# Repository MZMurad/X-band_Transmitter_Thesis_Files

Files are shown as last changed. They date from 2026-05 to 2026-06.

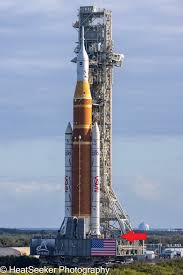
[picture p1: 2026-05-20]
GNU_Radio_Files/BPSK_TX_RX/Images.jpeg

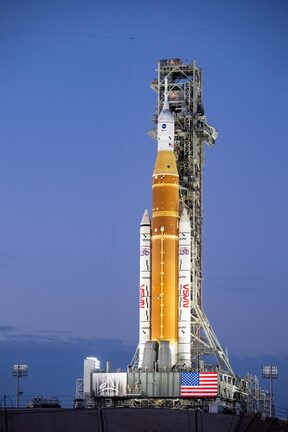
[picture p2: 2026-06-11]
GNU_Radio_Files/QPSK_TX_RX/images.jpeg

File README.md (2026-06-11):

# X-band_Transmitter_Thesis_Files
This is a repo for all the files used and mentioned in my thesis

The file structure:
    
- Hardware: Includes all KiCad schematics and PCBs, all are KiCad projects
- All GNU Radio flow graphs wthin the GNU labeled folder
- The python folder contains all python used for plotting and test automation for the HP5262A VNA and the HP8562A Spectrum Analyzer
- The data folder contains all data collected over the span of this thesis

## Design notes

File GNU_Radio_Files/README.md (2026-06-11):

# GNU Radio
The above two folders contain the flow graphs for a BPSK TX/RX that was used during this project's testing
The second folder contains a differential QPSK TX/RX flow graphs that were used in this project's testing

These files were made with the LimeSDR Mini 2

To use the files:
- After cloning the git, within each TX and RX flow graph there is either a file source or a file sink
- Each of these blocks must be given a path to a source file (png, jpeg, or text) and a sink file
- The sink file will always be overwritten, make sure the sink file has the same extention as the source file
- Before running the graphs on a full system ensure that you can connect two SDRs with a cable (TX -> RX) and that the files are operational without any hardware in the loop

Some trouble shooting tips
- A lot of the time it is helpful to understand what each block does, make sure you read the GNU Wiki. The wiki also has examples that these files are based on.
- Make sure the gain of the TX and RX stages are in order, the files here have the gains used with hardware in the loop
- The bandwidth of the FLL block and costas loops are very important for synchonization. If you suspect there might be some synchonizing issues it is a good idea to start there
- The Access code correlation block has a threshold value that is set to 0 meaning that the block will only trigger "correct" if there are no bit errors, this is useful but depending on the system in between the SDRs may need to be increased.

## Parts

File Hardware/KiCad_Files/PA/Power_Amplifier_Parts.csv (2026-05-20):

Reference | Value | Datasheet | Footprint | Qty | DNP
C1,C2,C3,C4,C5,C6,C7,C8 | 0.001u | ~ | Capacitor_SMD:C_0402_1005Metric_Pad0.74x0.62mm_HandSolder | 8
C9,C10,C11,C12,C13,C14,C15,C16,C18,C19,C20 | 0.1u | ~ | Capacitor_SMD:C_0402_1005Metric_Pad0.74x0.62mm_HandSolder | 11
C17 | 47u | ~ | Capacitor_SMD:C_1206_3216Metric | 1
IC1 | PMA5-123-3W+ | https://www.minicircuits.com/pdfs/PMA5-123-3W+.pdf | PMA5-123-3W+:QFN50P500X500X100-33N-D | 1
J1,J8 | 32K243-40ML5 | 32K243-40ML5 | 32K243-40ML5:CONN_32K243-40ML5_RBG | 2
J2,J3,J4,J5,J6,J7 | Conn_01x02_Pin | ~ | Connector_PinHeader_2.54mm:PinHeader_1x02_P2.54mm_Vertical | 6
L1,L2 | 150n | ~ | Inductor_SMD:L_0402_1005Metric_Pad0.77x0.64mm_HandSolder | 2
R1,R2 | 100k | ~ | Resistor_SMD:R_0402_1005Metric_Pad0.72x0.64mm_HandSolder | 2
R3 | 0R | ~ | Resistor_SMD:R_0402_1005Metric_Pad0.72x0.64mm_HandSolder | 1
R4 | 100R | ~ | Resistor_SMD:R_0402_1005Metric_Pad0.72x0.64mm_HandSolder | 1

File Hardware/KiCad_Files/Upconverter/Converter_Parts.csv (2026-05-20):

Value | Reference | Datasheet | Footprint | Qty | DNP
0.1u | C1,C2,C4,C17,C23,C25,C27,C29,C31,C34,C48 | ~ | Capacitor_SMD:C_0402_1005Metric_Pad0.74x0.62mm_HandSolder | 11
10p | C3,C6,C9 | ~ | Capacitor_SMD:C_0201_0603Metric_Pad0.64x0.40mm_HandSolder | 3
1000p | C5,C7,C8,C16,C37,C40,C43,C46 | ~ | Capacitor_SMD:C_0402_1005Metric_Pad0.74x0.62mm_HandSolder | 8
2p | C10,C11 | ~ | Capacitor_SMD:C_0402_1005Metric_Pad0.74x0.62mm_HandSolder | 2
0.47u | C12 | ~ | Capacitor_SMD:C_0603_1608Metric_Pad1.08x0.95mm_HandSolder | 1
22n | C13 | ~ | Capacitor_SMD:C_0603_1608Metric_Pad1.08x0.95mm_HandSolder | 1
1000p | C14 | ~ | Capacitor_SMD:C_0603_1608Metric_Pad1.08x0.95mm_HandSolder | 1
10p | C15 | ~ | Capacitor_SMD:C_0603_1608Metric_Pad1.08x0.95mm_HandSolder | 1
120p | C18,C21 | ~ | Capacitor_SMD:C_0603_1608Metric_Pad1.08x0.95mm_HandSolder | 2
1u | C19 | ~ | Capacitor_SMD:C_0603_1608Metric_Pad1.08x0.95mm_HandSolder | 1
0.1u | C20 | ~ | Capacitor_SMD:C_0603_1608Metric_Pad1.08x0.95mm_HandSolder | 1
10p | C22,C24,C26,C28,C30,C32,C35,C38,C39,C42,C45 | ~ | Capacitor_SMD:C_0402_1005Metric_Pad0.74x0.62mm_HandSolder | 11
DNP(1u) | C33 | ~ | Capacitor_SMD:C_0402_1005Metric_Pad0.74x0.62mm_HandSolder | 1
4.7u | C36 | ~ | Capacitor_SMD:C_0402_1005Metric_Pad0.74x0.62mm_HandSolder | 1
10u | C41 | ~ | Capacitor_SMD:C_0402_1005Metric_Pad0.74x0.62mm_HandSolder | 1
1u | C44,C47 | ~ | Capacitor_SMD:C_0402_1005Metric_Pad0.74x0.62mm_HandSolder | 2
LED | D1 | ~ | LED_SMD:LED_0603_1608Metric_Pad1.05x0.95mm_HandSolder | 1
32K243-40ML5 | J1,J2,J4,J5,J6,J8,J9,J10 | 32K243-40ML5 | 32K243-40ML5:CONN_32K243-40ML5_RBG | 8
MM8030-2610RK0 | J3,J16,J17,J19 | MM8030-2610RK0 | MM8030_2610RJ3:MM8030-2610RK0_MUR | 4
Conn_01x05_Pin | J7 | ~ | Connector_PinHeader_2.54mm:PinHeader_1x05_P2.54mm_Vertical | 1
Conn_01x03_Pin | J13,J14,J15,J20,J21 | ~ | Connector_PinHeader_2.54mm:PinHeader_1x03_P2.54mm_Vertical | 5
Conn_01x07_Pin | J18 | ~ | Connector_PinHeader_2.54mm:PinHeader_1x07_P2.54mm_Vertical | 1
DNP(4.7n) | L1,L3,L4 | ~ | Inductor_SMD:L_0201_0603Metric_Pad0.64x0.40mm_HandSolder | 3
7.4n | L2,L6 | ~ | Inductor_SMD:L_0201_0603Metric_Pad0.64x0.40mm_HandSolder | 2
10R | R1,R20 | ~ | Resistor_SMD:R_0402_1005Metric_Pad0.72x0.64mm_HandSolder | 2
100R | R3 | ~ | Resistor_SMD:R_0402_1005Metric_Pad0.72x0.64mm_HandSolder | 1
1.8k | R4,R5,R6 | ~ | Resistor_SMD:R_0603_1608Metric_Pad0.98x0.95mm_HandSolder | 3
1.5k | R7 | ~ | Resistor_SMD:R_0603_1608Metric_Pad0.98x0.95mm_HandSolder | 1
10k | R8 | ~ | Resistor_SMD:R_0603_1608Metric_Pad0.98x0.95mm_HandSolder | 1
0R | R9,R12,R13,R14,R19 | ~ | Resistor_SMD:R_0603_1608Metric_Pad0.98x0.95mm_HandSolder | 5
220 | R10 | ~ | Resistor_SMD:R_0603_1608Metric_Pad0.98x0.95mm_HandSolder | 1
470R | R11 | ~ | Resistor_SMD:R_0603_1608Metric_Pad0.98x0.95mm_HandSolder | 1
68R | R15 | ~ | Resistor_SMD:R_0603_1608Metric_Pad0.98x0.95mm_HandSolder | 1
0R | R16,R17 | ~ | Resistor_SMD:R_0201_0603Metric_Pad0.64x0.40mm_HandSolder | 2
5.1k | R18 | ~ | Resistor_SMD:R_0603_1608Metric_Pad0.98x0.95mm_HandSolder | 1
TestPoint | TP1 | ~ | TestPoint:TestPoint_Pad_D1.5mm | 1
TestPoint | TP6,TP7 | ~ | TestPoint:TestPoint_Pad_D1.0mm | 2
MFBP-00094PSM | U1 |  | Thesis_Marki:QFN-32_EP_5x5_Pitch0.5mm | 1
MFBA-00004PSM | U2 |  | Thesis_Marki:QFN-32_EP_5x5_Pitch0.5mm | 1
ADF5355BCPZ | U3 | https://www.analog.com/media/en/technical-documentation/data-sheets/ADF5355.pdf | ADF5355BCPZ:CP-32-12_ADI | 1
MM1-0222LSM-2 | U6 |  | Thesis_Marki:QFN-16_EP_3x3_Pitch0.5mm | 1
APM-7516PSM | U8,U10 |  | Thesis_Marki:QFN-24_EP_4x4_Pitch0.5mm | 2

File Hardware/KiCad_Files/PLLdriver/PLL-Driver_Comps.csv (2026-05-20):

Reference | Value | Datasheet | Footprint | Qty | DNP
C1,C2 | 100p | ~ | Capacitor_SMD:C_0402_1005Metric_Pad0.74x0.62mm_HandSolder | 2
C3,C4 | 0.3p | ~ | Capacitor_SMD:C_0402_1005Metric_Pad0.74x0.62mm_HandSolder | 2
C5 | 10p | ~ | Capacitor_SMD:C_0402_1005Metric_Pad0.74x0.62mm_HandSolder | 1
C6 | 1u | ~ | Capacitor_SMD:C_0402_1005Metric_Pad0.74x0.62mm_HandSolder | 1
C7 | 10u | ~ | Capacitor_SMD:C_0603_1608Metric_Pad1.08x0.95mm_HandSolder | 1
J1,J2 | 32K243-40ML5 | 32K243-40ML5 | 32K243-40ML5:CONN_32K243-40ML5_RBG | 2
J3,J4 | Conn_01x02_Pin | ~ | Connector_PinHeader_2.54mm:PinHeader_1x02_P2.54mm_Vertical | 2
L1 | 33nH | ~ | Inductor_SMD:L_0603_1608Metric_Pad1.05x0.95mm_HandSolder | 1
U1 | PMA3-83MP+ | PMA3-83MP+ | PMA3-83MP:DQ1225_MNC | 1

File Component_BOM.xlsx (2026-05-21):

 |  | Up Converter
Value | Discription | Size | Count | Part Link | Part Number
0.1u | Cap | 0402 | 33 | https://www.mouser.com/ProductDetail/TAIYO-YUDEN/MMASU105SB5104KFNA01 | MMASU105SB5104KFNA01
10p | Cap | 0201 | 15 | https://www.digikey.com/en/products/detail/murata-electronics/GRM1885C1H100JA01D/586930 | GRM1885C1H100JA01D
1000p | Cap | 0402 | 15 | https://www.mouser.com/ProductDetail/KYOCERA-AVX/04025A102FAT2A | 04025A102FAT2A
2p | Cap | 0402 | 10 | https://www.mouser.com/ProductDetail/KYOCERA-AVX/04025J2R0QBSTR | 04025J2R0QBSTR
0.47u | Cap | 0603 | 15 | https://www.mouser.com/ProductDetail/KEMET/C0603C474J3RACTU?qs=HoCaDK9Nz5dEncza6kTYlQ%3D%3D | C0603C474J3RACTU
22n | Cap | 0603 | 15 | https://www.mouser.com/ProductDetail/KYOCERA-AVX/0603YC223KAT2A?qs=394Pi71zH6hTiH4tlhTRbQ%3D%3D | 0603YC223KAT2A
1000p | Cap | 0603 | 15 | https://www.digikey.com/en/products/detail/yageo/CC0603KRX7R9BB103/302819?gclsrc=aw.ds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 | CC0603KRX7R9BB103
10p | Cap | 0603 | 15 | https://www.mouser.com/ProductDetail/KEMET/C0603C100F2TACTU?qs=Znm5pLBrcAL25eSJc5nVFw%3D%3D | C0603C100F2TACTU
120p | Cap | 0603 | 15 | https://www.mouser.com/ProductDetail/KYOCERA-AVX/06031U121FAT2A | 06031U121FAT2A
1u | Cap | 0603 | 15 | https://www.mouser.com/ProductDetail/YAGEO/CC0603KRX5R8BB105 | CC0603KRX5R8BB105
0.1u | Cap | 0603 | 15 | https://www.mouser.com/ProductDetail/YAGEO/CC0603MRY5V9BB104 | CC0603MRY5V9BB104
10p | Cap | 0402 | 33 | https://www.mouser.com/ProductDetail/Vishay-Vitramon/VJ0402D100FXCAJ | VJ0402D100FXCAJ
4.7u | Cap | 0402 | 15 | https://www.mouser.com/ProductDetail/KYOCERA-AVX/04023D475MAT2A | 04023D475MAT2A
10u | Cap | 0402 | 15 | https://www.mouser.com/ProductDetail/KYOCERA-AVX/0402ZD106MAT4A?qs=OlC7AqGiEDknQdNq3NcrYg%3D%3D | 0402ZD106MAT4A
1u | Cap | 0402 | 15 | https://www.mouser.com/ProductDetail/KYOCERA-AVX/04023D105KAT2A | 04023D105KAT2A
LED | Diode | 0603 | 5 | https://www.mouser.com/ProductDetail/ams-OSRAM/Q65113A7466?qs=wT7LY0lnAe3Xiz4Rd%252BLMUA%3D%3D | Q65113A7466
32K243-40ML5 | RF Connector | ~ | 8 | https://www.mouser.com/ProductDetail/Rosenberger/32K243-40ML5?qs=ehM%252BESVsXgwT7KyEp9wcmQ%3D%3D | 32K243-40ML5
MM8030-2610RK0 | RF Connector | ~ | 4 | https://www.digikey.com/en/products/detail/murata-electronics/MM8030-2610RK0/4421021 | MM8030-2610RK0
DNP(4.7n) | Ind | 0201 | 15 | https://www.mouser.com/ProductDetail/ABRACON/AIMC-Q0201HQ-4N7H-T?qs=ST9lo4GX8V2VU3SnVgirQg%3D%3D | AIMC-Q0201HQ-4N7H-T
7.4n | Ind | 0201 | 15 | https://www.digikey.com/en/products/detail/coilcraft/0201DS-7N4XJEW/15794125 | 0201DS-7N4XJEW
10R | Res | 0402 | 15 | https://www.mouser.com/ProductDetail/Vishay-Beyschlag/MCS04020C1009DE000 | MCS04020C1009DE000
100R | Res | 0402 | 15 | https://www.mouser.com/ProductDetail/Bourns/CR0402-JW-101GLF | CR0402-JW-101GLF
1.8k | Res | 0603 | 15 | https://www.mouser.com/ProductDetail/Vishay/TNPW06031K80DETA | TNPW06031K80DETA
1.5k | Res | 0603 | 15 | https://www.mouser.com/ProductDetail/Bourns/CR0603-JW-152ELF?qs=wOX%252BDVkMoZSu%252BfxzrcTI6Q%3D%3D | CR0603-JW-152ELF
10k | Res | 0603 | 15 | https://www.mouser.com/ProductDetail/Vishay-Beyschlag/MCT06030D1002BPW00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 | MCT06030D1002BPW00
0R | Res | 0603 | 15 | https://www.mouser.com/ProductDetail/Vishay/CRCW06030000Z0EI | CRCW06030000Z0EI
220R | Res | 0603 | 15 | https://www.mouser.com/ProductDetail/Bourns/CR0603-JW-221ELF | CR0603-JW-221ELF
470R | Res | 0603 | 15 | https://www.mouser.com/ProductDetail/Bourns/CR0603-JW-471ELF?qs=sGAEpiMZZMtlubZbdhIBIN4pzcyTCT7wAWvNAcavl80%3D | CR0603-JW-471ELF
68R | Res | 0603 | 15 | https://www.mouser.com/ProductDetail/Vishay-Beyschlag/MCT06030C6809FP500 | MCT06030C6809FP500
0R | Res | 0201 | 15 | https://www.mouser.com/ProductDetail/Vishay/RCA02010000ZSEDSR | RCA02010000ZSEDSR
5.1k | Res | 0603 | 15 | https://www.mouser.com/ProductDetail/Bourns/CR0603-FX-5101ELF?qs=0nF2VnfAjXkzZl7D0jRjmQ%3D%3D | CR0603-FX-5101ELF
ADF5355BCPZ | PLL | ~ | 2 | https://www.mouser.com/ProductDetail/Analog-Devices/ADF5355BCPZ?qs=hpwIUhX6lWz%252By8O4aZ7X5w%3D%3D | ADF5355BCPZ
Header 2.54mm | Connector |  | 20 | https://www.digikey.com/en/products/detail/adam-tech/PH1-10-UA/9830653?gclsrc=aw.ds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 | PH1-10-UA
 |  | PA
Value | Discription | Size | Count | Part Link | Part Number
0.001u | Cap | 0402 | 15 | https://www.digikey.com/en/products/detail/murata-electronics/GRM1555C1H102JA01D/702509 | GRM1555C1H102JA01D
0.1u | Cap | 0402 | 33 | https://www.digikey.com/en/products/detail/murata-electronics/GRM155R71E104KE14D/4905173 | GRM155R71E104KE14D
47u | Cap | 1206 | 15 | https://www.digikey.com/en/products/detail/kyocera-avx/KGM31HR51C476MU/13557231 | KGM31HR51C476MU
PMA5-123-3W+ | PA | ~ | 2 | https://www.mouser.com/ProductDetail/Mini-Circuits/PMA5-123-3W%2b?qs=sqEgtWRSLJ2vtugGWqj06A%3D%3D | PMA5-123-3W+
32K243-40ML5 | Conn | ~ | 2 | https://www.mouser.com/ProductDetail/Rosenberger/32K243-40ML5?qs=ehM%252BESVsXgwT7KyEp9wcmQ%3D%3D | 32K243-40ML5
150n | Ind | 0402 | 7 | https://www.digikey.com/en/products/detail/coilcraft/0402DF-151XJRW/12714460 | 0402DF-151XJRW
100k | Res | 0402 | 15 | https://www.digikey.com/en/products/detail/koa-speer-electronics-inc/RK73H1ETTP1003F/9844156 | RK73H1ETTP1003F
0R | Res | 0402 | 15 | https://www.digikey.com/en/products/detail/koa-speer-electronics-inc/RK73Z1ETTP/9844696 | RK73Z1ETTP
100R | Res | 0402 | 15 | https://www.digikey.com/en/products/detail/koa-speer-electronics-inc/RK73H1ETTP1000F/9844157 | RK73H1ETTP1000F
 |  | PLL-Driver
Value | Discription | Size | Count | Part Link | Part Number
100p | Cap | 0402 | 15 | https://www.digikey.com/en/products/detail/murata-electronics/GRM1555C1H101JA01D/3693829 | GRM1555C1H101JA01D
0.3p | Cap | 0402 | 15 | https://www.digikey.com/en/products/detail/murata-electronics/GQM1555C2DR30WB01D/5881897 | GQM1555C2DR30WB01D
10p | Cap | 0402 | 15 | https://www.digikey.com/en/products/detail/murata-electronics/GRM1555C1H100JA01D/3661907 | GRM1555C1H100JA01D
1u | Cap | 0402 | 15 | https://www.digikey.com/en/products/detail/murata-electronics/GRM155C71A105KE11D/6606086 | GRM155C71A105KE11D
10u | Cap | 0603 | 15 | https://www.digikey.com/en/products/detail/murata-electronics/GRM188D71A106MA73J/4905330 | GRM188D71A106MA73J
32K243-40ML5 | Conn | ~ | 2 | https://www.mouser.com/ProductDetail/Rosenberger/32K243-40ML5?qs=ehM%252BESVsXgwT7KyEp9wcmQ%3D%3D | 32K243-40ML5
33nH | Ind | 0603 | 7 | https://www.digikey.com/en/products/detail/coilcraft/0603CS-33NXGRW/21381206 | 0603CS-33NXGRW
PMA3-83MP+ | Amp | ~ | 2 | https://www.digikey.com/en/products/detail/mini-circuits/PMA3-83MP/16515860 | PMA3-83MP

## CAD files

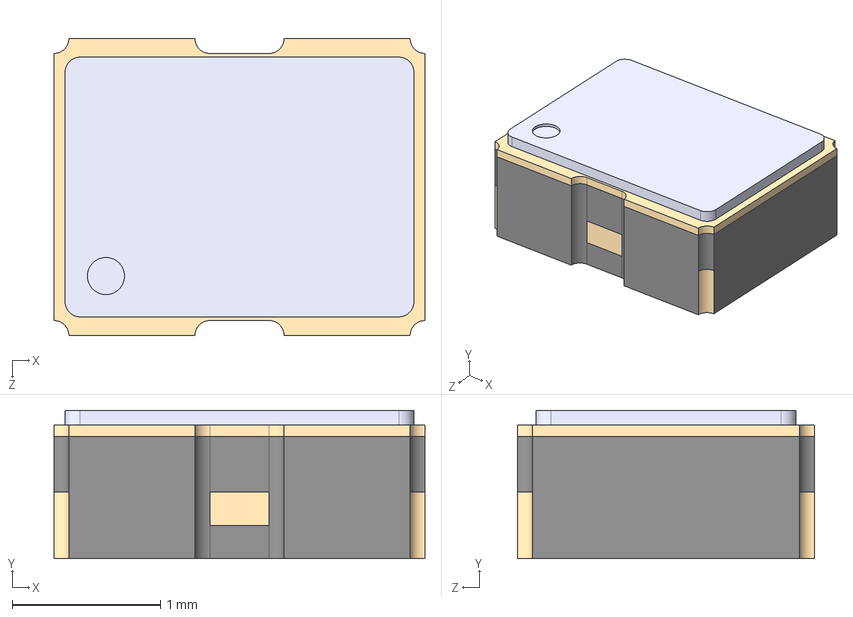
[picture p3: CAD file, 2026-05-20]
Hardware/KiCad_Files/00_OOTparts/ECS-TXO-2520 - TCXO/ECS_TXO_2520_33_250_AN_TR/ECS-TXO-2520-33-250-AN-TR.step
2.50 x 1.00 x 2.00 mm

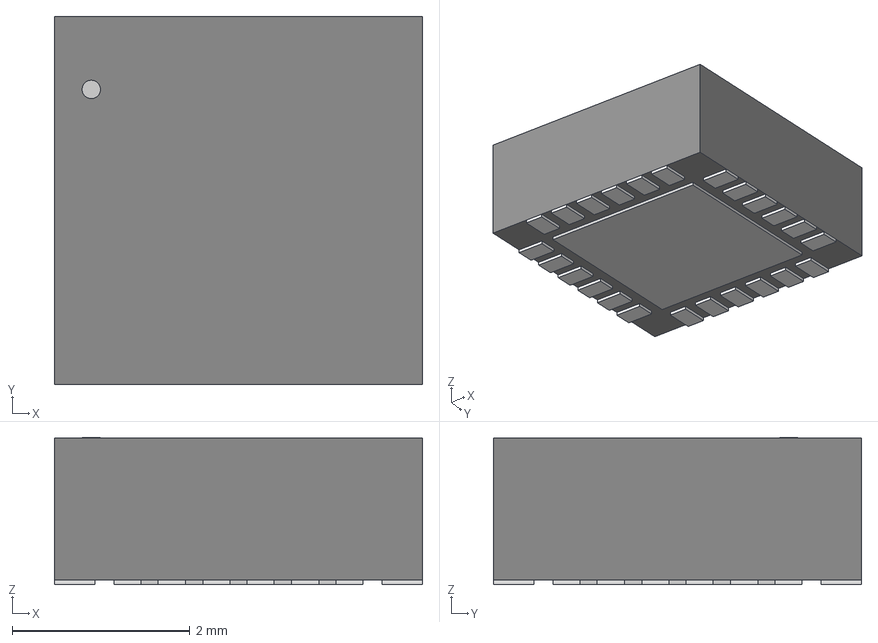
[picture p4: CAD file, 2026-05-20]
Hardware/KiCad_Files/00_OOTparts/S2-LP - Trans/S2_LPQTR/QFN_PQTR_STM.step
4.14 x 4.14 x 1.65 mm

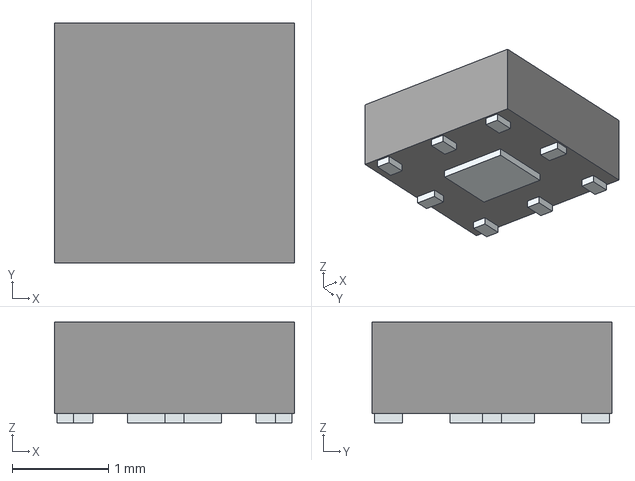
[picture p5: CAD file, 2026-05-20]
Hardware/KiCad_Files/00_OOTparts/Thesis/LIB_MBT-44+ Bias T/LIB_MBT-44+/MBT-44+/3D/MBT-44+.stp
2.50 x 2.50 x 1.05 mm
Pins

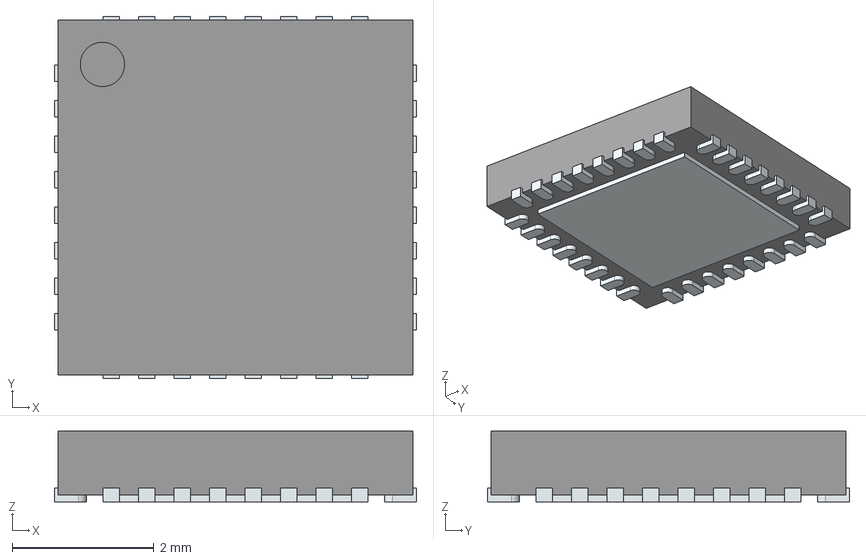
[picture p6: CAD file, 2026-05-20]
Hardware/KiCad_Files/00_OOTparts/Thesis/PMA5-123-3W+ - PA/LIB_PMA5-123-3W+/PMA5-123-3W+/3D/PMA5-123-3W+.stp
5.10 x 5.10 x 1.00 mm
ThermalPin
PinsArrayLR
PinsArrayTB

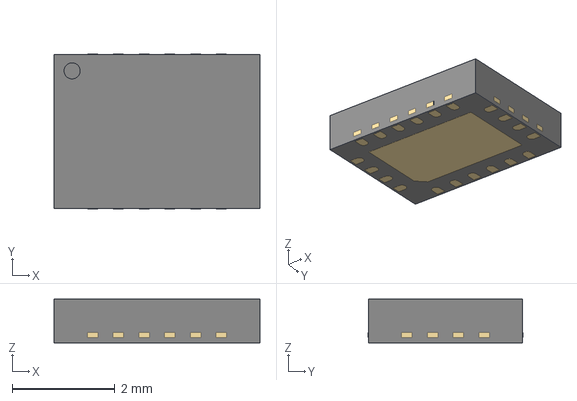
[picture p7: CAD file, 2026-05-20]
Hardware/KiCad_Files/00_OOTparts/Thesis/QPA0001 - Quorvo PA/LIB_QPA0001/QPA0001/3D/QPA0001.stp
4.00 x 3.00 x 0.851 mm

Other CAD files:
Hardware/KiCad_Files/00_OOTparts/Thesis/LIB_MBT-44+ Bias T/LIB_MBT-44+/MBT-44+/Allegro/mbt44.psm
Hardware/KiCad_Files/00_OOTparts/Thesis/LIB_MBT-44+ Bias T/LIB_MBT-44+/MBT-44+/DEHDL/mbt_44_/chips/chips.prt
Hardware/KiCad_Files/00_OOTparts/Thesis/PMA5-123-3W+ - PA/LIB_PMA5-123-3W+/PMA5-123-3W+/Allegro/qfn50p500x500x100-33n-d.psm
Hardware/KiCad_Files/00_OOTparts/Thesis/PMA5-123-3W+ - PA/LIB_PMA5-123-3W+/PMA5-123-3W+/DEHDL/pma5_123_3w_/chips/chips.prt

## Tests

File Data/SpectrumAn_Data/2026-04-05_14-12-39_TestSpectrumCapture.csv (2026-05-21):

Date: 2026-04-05_14-12-39
Center Frequency (Hz): 7600000000.0
Span (Hz): 9700000000.0
RBW (Hz): 2000000.0
Frequency (Hz) | Power (dBm)
2.750000000000000000e+09 | -4.382999999999999829e+01
2.766166666666666508e+09 | -7.132999999999999829e+01
2.782333333333333492e+09 | -4.415999999999999659e+01
2.798500000000000000e+09 | -7.215999999999999659e+01
2.814666666666666508e+09 | -4.315999999999999659e+01
2.830833333333333492e+09 | -7.215999999999999659e+01
2.847000000000000000e+09 | -4.300000000000000000e+01
2.863166666666666508e+09 | -7.065999999999999659e+01
2.879333333333333492e+09 | -4.350000000000000000e+01
2.895500000000000000e+09 | -7.432999999999999829e+01
2.911666666666666508e+09 | -4.265999999999999659e+01
2.927833333333333492e+09 | -7.565999999999999659e+01
2.944000000000000000e+09 | -4.165999999999999659e+01
2.960166666666666508e+09 | -7.350000000000000000e+01
2.976333333333333492e+09 | -4.382999999999999829e+01
2.992500000000000000e+09 | -7.300000000000000000e+01
3.008666666666666508e+09 | -4.432999999999999829e+01
3.024833333333333492e+09 | -7.315999999999999659e+01
3.041000000000000000e+09 | -4.482999999999999829e+01
3.057166666666666508e+09 | -7.550000000000000000e+01
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

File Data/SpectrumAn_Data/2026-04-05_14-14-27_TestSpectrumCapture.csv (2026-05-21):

Date: 2026-04-05_14-14-27
Center Frequency (Hz): 7600000000.0
Span (Hz): 9700000000.0
RBW (Hz): 2000000.0
ID: 8562A GPIB0::18::INSTRFrequency (Hz) | Power (dBm)
2.750000000000000000e+09 | -4.382999999999999829e+01
2.766166666666666508e+09 | -7.132999999999999829e+01
2.782333333333333492e+09 | -4.415999999999999659e+01
2.798500000000000000e+09 | -7.215999999999999659e+01
2.814666666666666508e+09 | -4.315999999999999659e+01
2.830833333333333492e+09 | -7.215999999999999659e+01
2.847000000000000000e+09 | -4.300000000000000000e+01
2.863166666666666508e+09 | -7.065999999999999659e+01
2.879333333333333492e+09 | -4.350000000000000000e+01
2.895500000000000000e+09 | -7.432999999999999829e+01
2.911666666666666508e+09 | -4.265999999999999659e+01
2.927833333333333492e+09 | -7.565999999999999659e+01
2.944000000000000000e+09 | -4.165999999999999659e+01
2.960166666666666508e+09 | -7.350000000000000000e+01
2.976333333333333492e+09 | -4.382999999999999829e+01
2.992500000000000000e+09 | -7.300000000000000000e+01
3.008666666666666508e+09 | -4.432999999999999829e+01
3.024833333333333492e+09 | -7.315999999999999659e+01
3.041000000000000000e+09 | -4.482999999999999829e+01
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

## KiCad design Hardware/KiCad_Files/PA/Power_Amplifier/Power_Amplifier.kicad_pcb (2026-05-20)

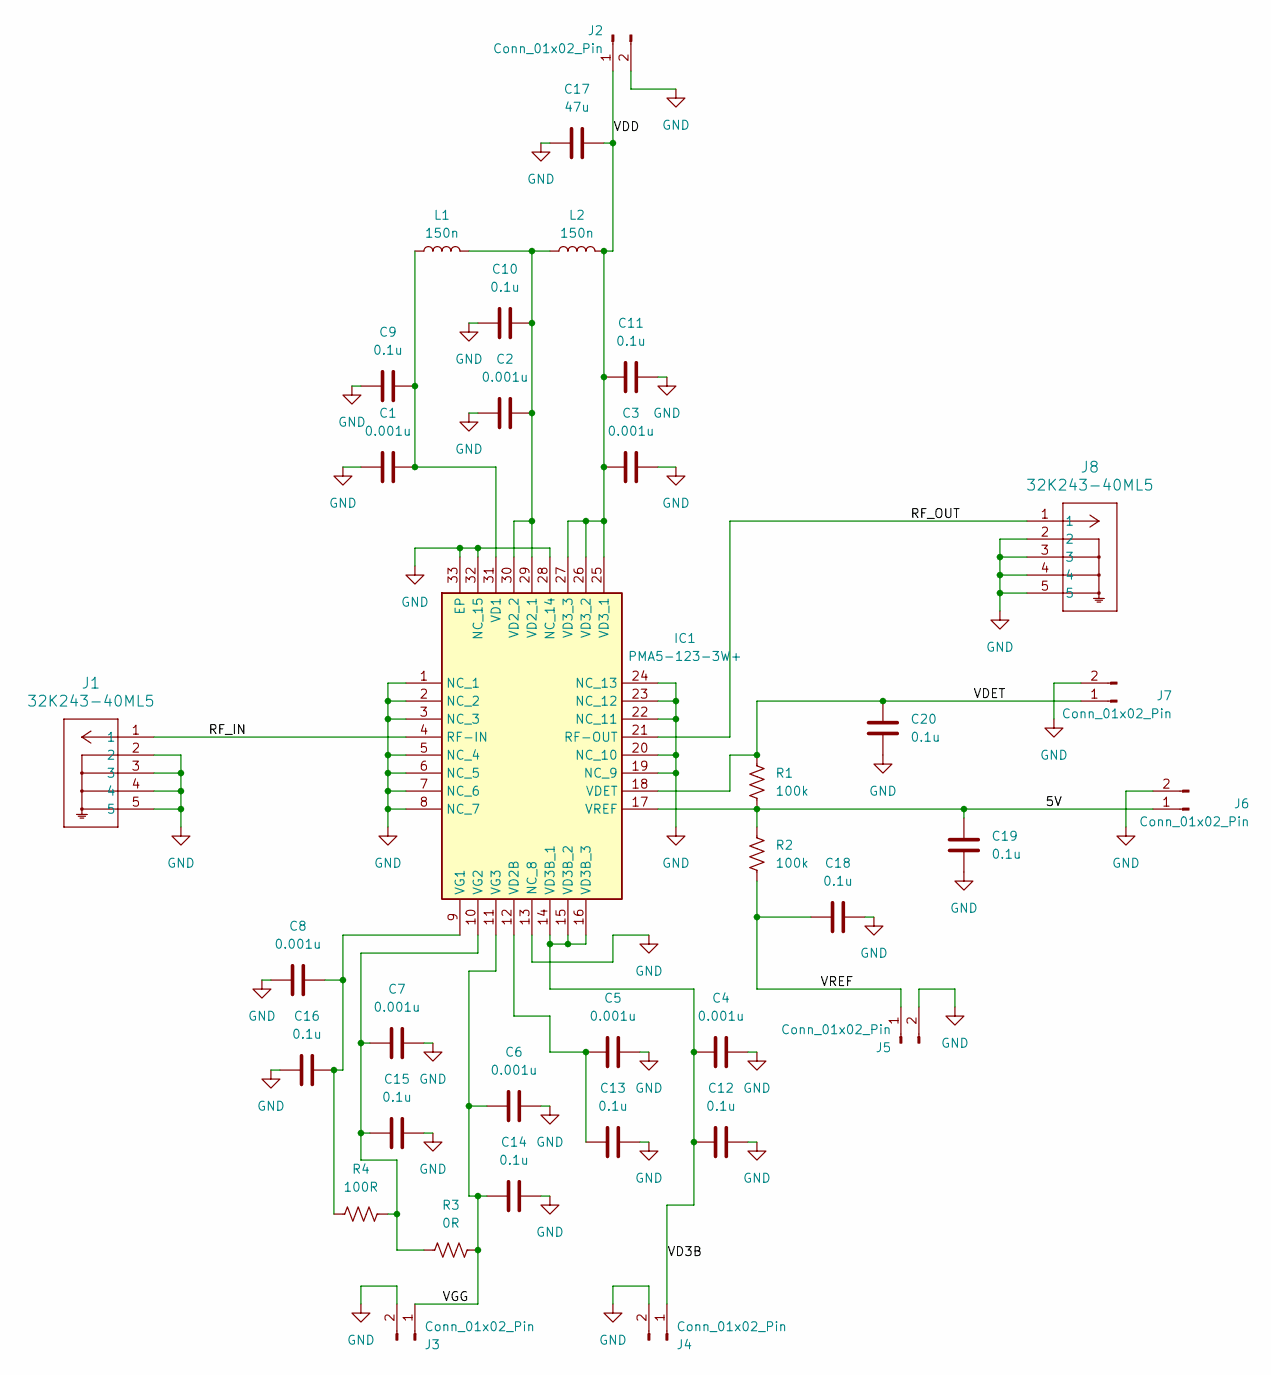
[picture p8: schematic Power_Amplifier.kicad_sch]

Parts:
C1, C2, C3, C4, C5, C6, C7, C8: 0.001u; C_0402_1005Metric_Pad0.74x0.62mm_HandSolder
C9, C10, C11, C12, C13, C14, C15, C16, C18, C19, C20: 0.1u; C_0402_1005Metric_Pad0.74x0.62mm_HandSolder
C17: 47u; C_1206_3216Metric
IC1: PMA5-123-3W+; QFN50P500X500X100-33N-D; Manufacturer_Part_Number PMA5-123-3W+
J1, J8: 32K243-40ML5; CONN_32K243-40ML5_RBG
J2, J3, J4, J5, J6, J7: Conn_01x02_Pin; PinHeader_1x02_P2.54mm_Vertical
L1, L2: 150n; L_0402_1005Metric_Pad0.77x0.64mm_HandSolder
R1, R2: 100k; R_0402_1005Metric_Pad0.72x0.64mm_HandSolder
R3: 0R; R_0402_1005Metric_Pad0.72x0.64mm_HandSolder
R4: 100R; R_0402_1005Metric_Pad0.72x0.64mm_HandSolder

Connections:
/5V: C19.1, IC1.17 (VREF), J6.1, R1.2, R2.1
/RF_IN: IC1.4 (RF-IN), J1.1
/RF_OUT: IC1.21 (RF-OUT), J8.1
/VD3B: C4.2, C12.2, IC1.14 (VD3B_1), IC1.15 (VD3B_2), IC1.16 (VD3B_3), J4.1
/VDD: C3.2, C11.1, C17.2, IC1.25 (VD3_1), IC1.26 (VD3_2), IC1.27 (VD3_3), J2.1, L2.2
/VDET: C20.1, IC1.18 (VDET), J7.1, R1.1
/VGG: C6.2, C14.2, IC1.11 (VG3), J3.1, R3.2
/VREF: C18.2, J5.1, R2.2
GND: C1.1, C2.1, C3.1, C4.1, C5.1, C6.1, C7.1, C8.1, C9.1, C10.1, C11.2, C12.1, C13.1, C14.1, C15.1, C16.1, C17.1, C18.1, C19.2, C20.2, IC1.1 (NC_1), IC1.2 (NC_2), IC1.3 (NC_3), IC1.5 (NC_4), IC1.6 (NC_5), IC1.7 (NC_6), IC1.8 (NC_7), IC1.13 (NC_8), IC1.19 (NC_9), IC1.20 (NC_10), IC1.22 (NC_11), IC1.23 (NC_12), IC1.24 (NC_13), IC1.28 (NC_14), IC1.32 (NC_15), IC1.33 (EP), J1.2, J1.3, J1.4, J1.5, J2.2, J3.2, J4.2, J5.2, J6.2, J7.2, J8.2, J8.3, J8.4, J8.5
unnamed: C1.2, C9.2, IC1.31 (VD1), L1.1
unnamed: C5.2, C13.2, IC1.12 (VD2B)
unnamed: C2.2, C10.2, IC1.29 (VD2_1), IC1.30 (VD2_2), L1.2, L2.1
unnamed: C8.2, C16.2, IC1.9 (VG1), R4.1
unnamed: C7.2, C15.2, IC1.10 (VG2), R3.1, R4.2

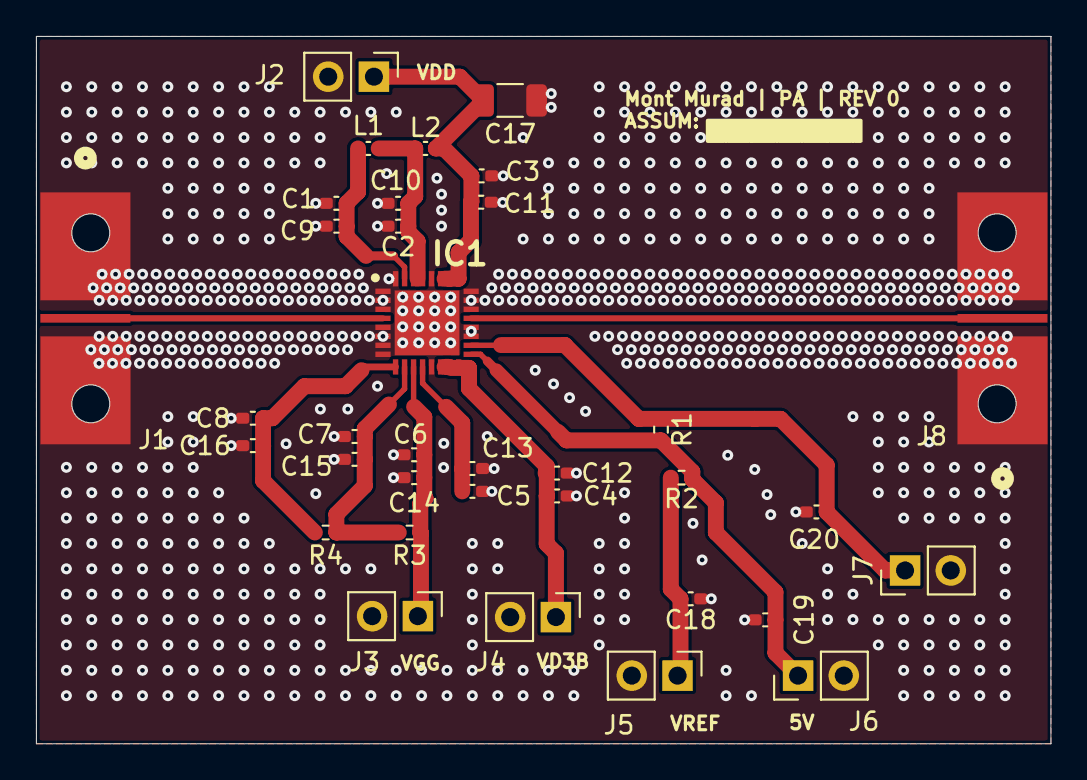
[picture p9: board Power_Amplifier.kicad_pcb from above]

Board: 4 copper layers, 56.4 x 39.3 mm, 35 parts (0 on the bottom side), 14 nets.

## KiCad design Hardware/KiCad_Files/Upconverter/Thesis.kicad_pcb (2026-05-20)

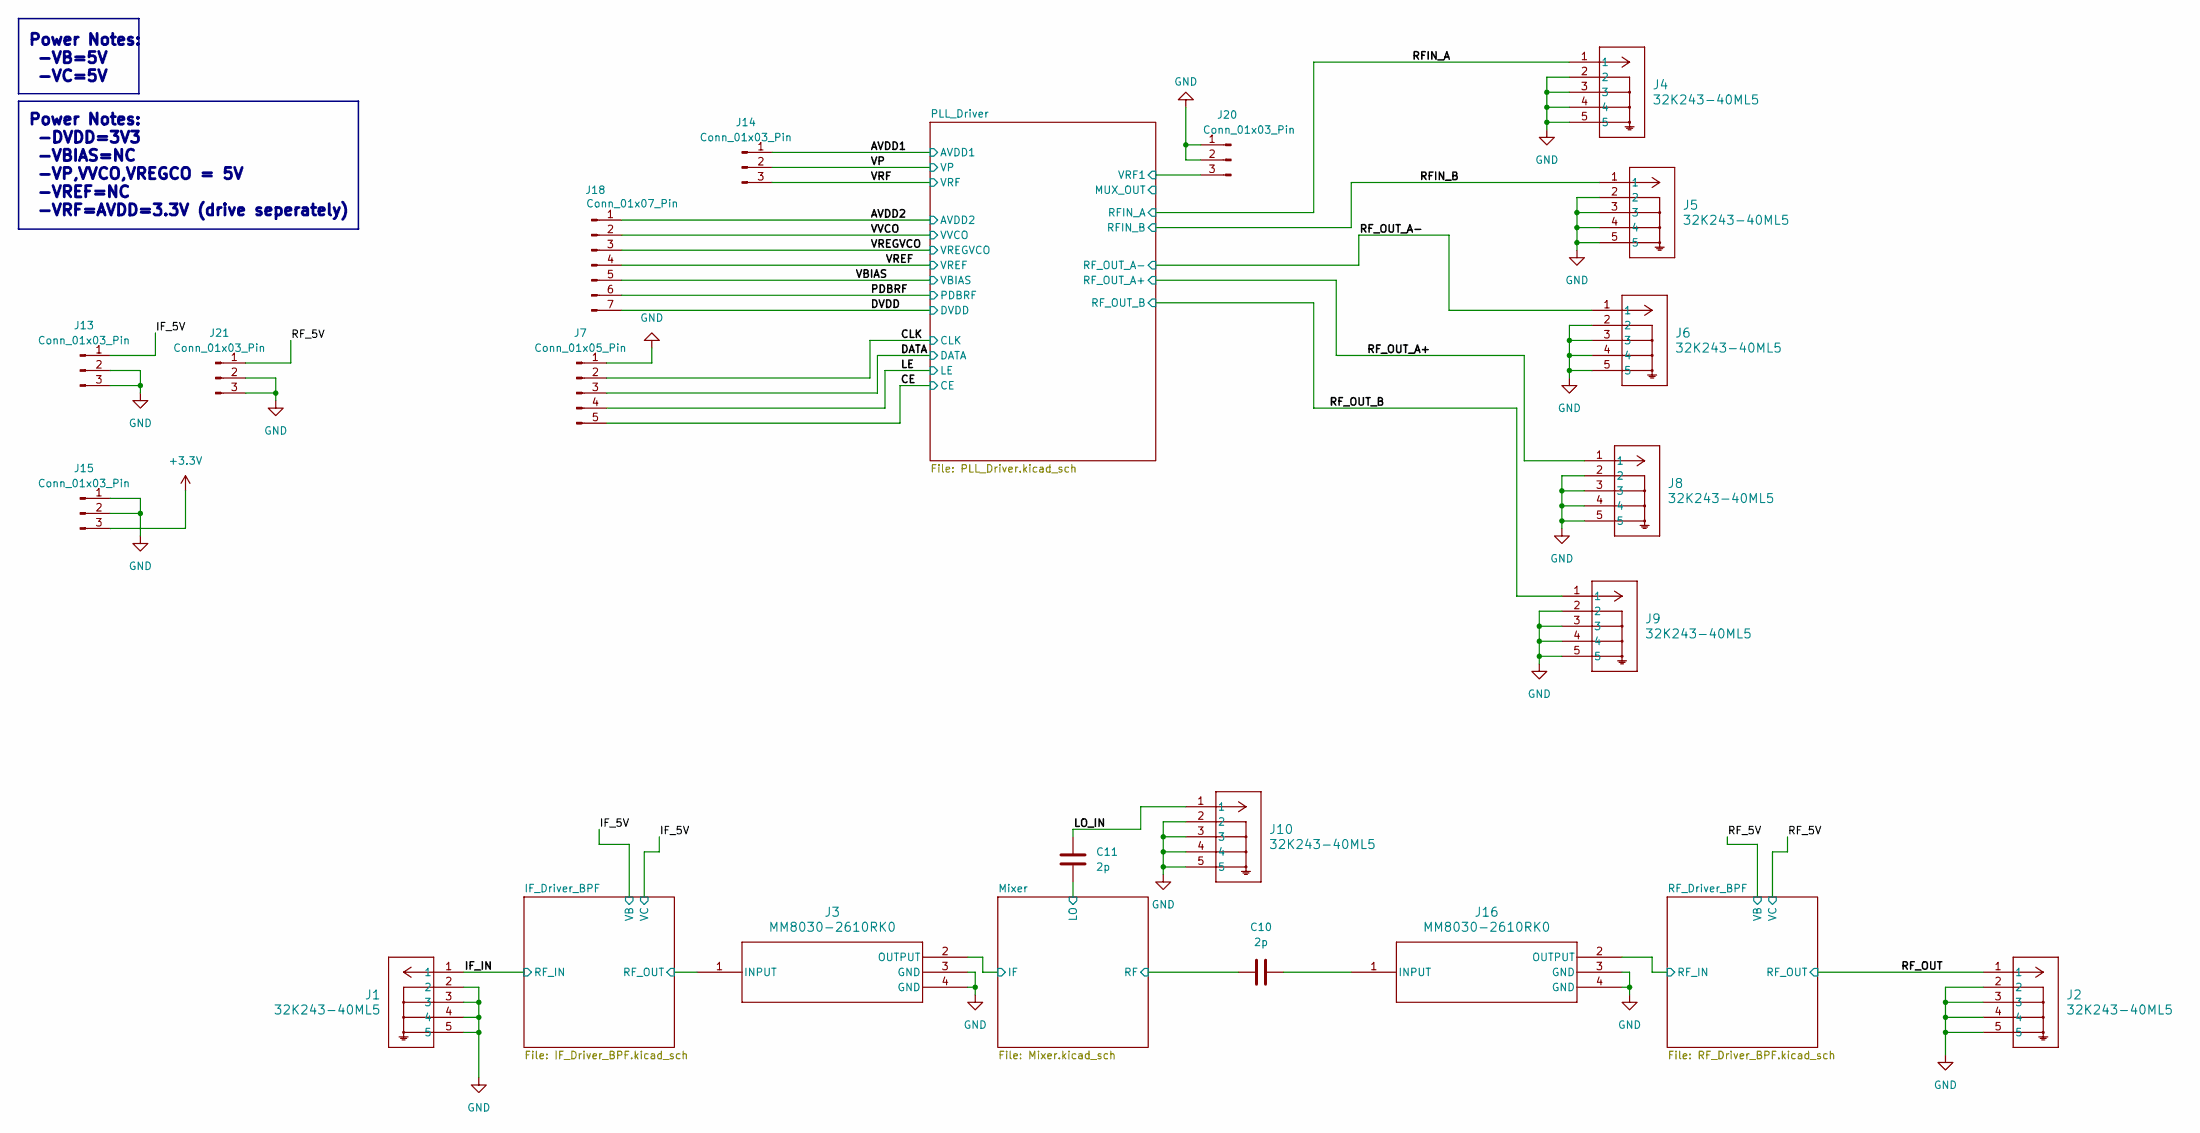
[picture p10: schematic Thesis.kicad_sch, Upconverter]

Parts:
C10, C11: 2p; C_0402_1005Metric_Pad0.74x0.62mm_HandSolder
J1, J2, J4, J5, J6, J8, J9, J10: 32K243-40ML5; CONN_32K243-40ML5_RBG
J3, J16: MM8030-2610RK0; MM8030-2610RK0_MUR
J7: Conn_01x05_Pin; PinHeader_1x05_P2.54mm_Vertical
J13, J14, J15, J20, J21: Conn_01x03_Pin; PinHeader_1x03_P2.54mm_Vertical
J18: Conn_01x07_Pin; PinHeader_1x07_P2.54mm_Vertical

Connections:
+3.3V: J15.3; also elsewhere on the board
/AVDD1: J14.1; also elsewhere on the board
/AVDD2: J18.1; also elsewhere on the board
/CE: J7.5; also elsewhere on the board
/CLK: J7.2; also elsewhere on the board
/DATA: J7.3; also elsewhere on the board
/DVDD: J18.7; also elsewhere on the board
/IF_5V: J13.1; also elsewhere on the board
/IF_Driver_BPF/RF_OUT: J3.1 (INPUT); also elsewhere on the board
/IF_IN: J1.1; also elsewhere on the board
/LE: J7.4; also elsewhere on the board
/LO_IN: C11.2, J10.1
/Mixer/IF: J3.2 (OUTPUT); also elsewhere on the board
/Mixer/LO: C11.1; also elsewhere on the board
/Mixer/RF: C10.1; also elsewhere on the board
/PDBRF: J18.6; also elsewhere on the board
/PLL_Driver/VRF1: J20.3; also elsewhere on the board
/RFIN_A: J4.1; also elsewhere on the board
/RFIN_B: J5.1; also elsewhere on the board
/RF_5V: J21.1; also elsewhere on the board
/RF_Driver_BPF/RF_IN: J16.2 (OUTPUT); also elsewhere on the board
/RF_OUT: J2.1; also elsewhere on the board
/RF_OUT_A+: J8.1; also elsewhere on the board
/RF_OUT_A-: J6.1; also elsewhere on the board
/RF_OUT_B: J9.1; also elsewhere on the board
/VBIAS: J18.5; also elsewhere on the board
/VP: J14.2; also elsewhere on the board
/VREF: J18.4; also elsewhere on the board
/VREGVCO: J18.3; also elsewhere on the board
/VRF: J14.3; also elsewhere on the board
/VVCO: J18.2; also elsewhere on the board
GND: J1.2, J1.3, J1.4, J1.5, J2.2, J2.3, J2.4, J2.5, J3.3 (GND), J3.4 (GND), J4.2, J4.3, J4.4, J4.5, J5.2, J5.3, J5.4, J5.5, J6.2, J6.3, J6.4, J6.5, J7.1, J8.2, J8.3, J8.4, J8.5, J9.2, J9.3, J9.4, J9.5, J10.2, J10.3, J10.4, J10.5, J13.2, J13.3, J15.1, J15.2, J16.3 (GND), J16.4 (GND), J20.1, J20.2, J21.2, J21.3; also elsewhere on the board
unnamed: C10.2, J16.1 (INPUT)

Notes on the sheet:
Power Notes: -DVDD=3V3 -VBIAS=NC -VP,VVCO,VREGCO = 5V -VREF=NC -VRF=AVDD=3.3V (drive seperately)
Power Notes: -VB=5V -VC=5V

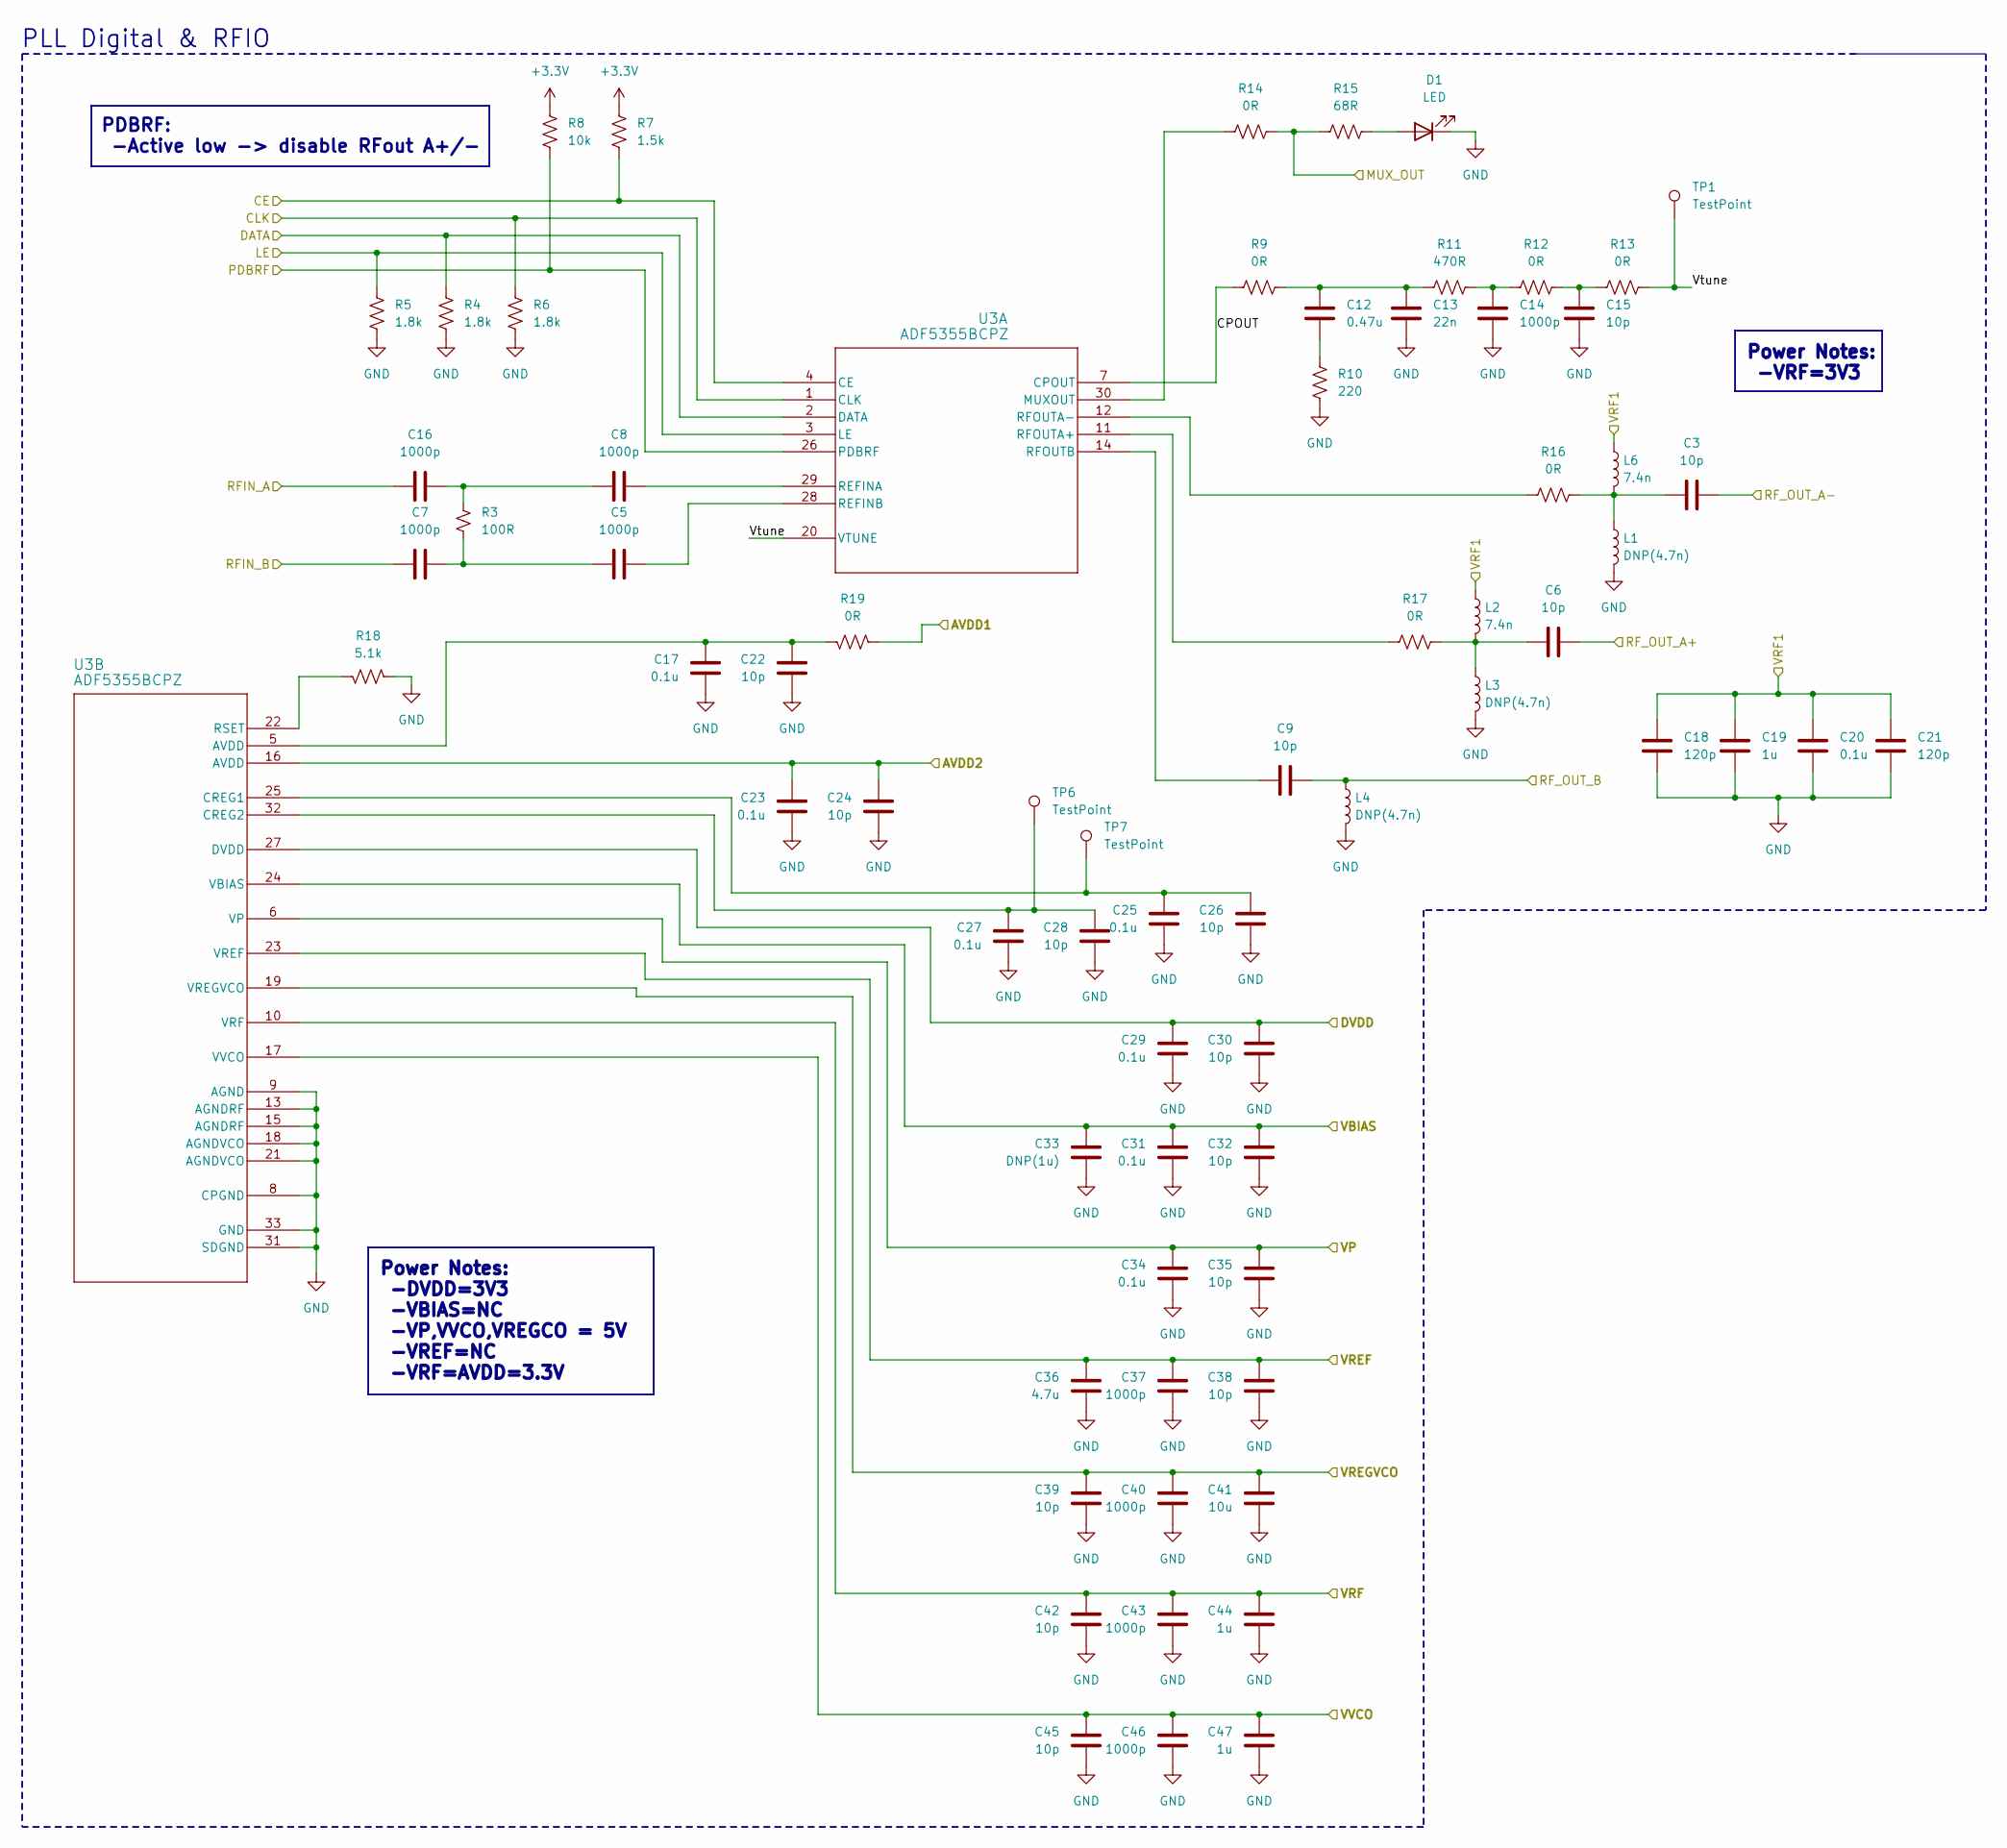
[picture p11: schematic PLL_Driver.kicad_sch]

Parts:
C3, C6, C9: 10p; C_0201_0603Metric_Pad0.64x0.40mm_HandSolder
C5, C7, C8, C16, C37, C40, C43, C46: 1000p; C_0402_1005Metric_Pad0.74x0.62mm_HandSolder
C12: 0.47u; C_0603_1608Metric_Pad1.08x0.95mm_HandSolder
C13: 22n; C_0603_1608Metric_Pad1.08x0.95mm_HandSolder
C14: 1000p; C_0603_1608Metric_Pad1.08x0.95mm_HandSolder
C15: 10p; C_0603_1608Metric_Pad1.08x0.95mm_HandSolder
C17, C23, C25, C27, C29, C31, C34: 0.1u; C_0402_1005Metric_Pad0.74x0.62mm_HandSolder
C18, C21: 120p; C_0603_1608Metric_Pad1.08x0.95mm_HandSolder
C19: 1u; C_0603_1608Metric_Pad1.08x0.95mm_HandSolder
C20: 0.1u; C_0603_1608Metric_Pad1.08x0.95mm_HandSolder
C22, C24, C26, C28, C30, C32, C35, C38, C39, C42, C45: 10p; C_0402_1005Metric_Pad0.74x0.62mm_HandSolder
C33: DNP(1u); C_0402_1005Metric_Pad0.74x0.62mm_HandSolder
C36: 4.7u; C_0402_1005Metric_Pad0.74x0.62mm_HandSolder
C41: 10u; C_0402_1005Metric_Pad0.74x0.62mm_HandSolder
C44, C47: 1u; C_0402_1005Metric_Pad0.74x0.62mm_HandSolder
D1: LED; LED_0603_1608Metric_Pad1.05x0.95mm_HandSolder
L1, L3, L4: DNP(4.7n); L_0201_0603Metric_Pad0.64x0.40mm_HandSolder
L2, L6: 7.4n; L_0201_0603Metric_Pad0.64x0.40mm_HandSolder
R3: 100R; R_0402_1005Metric_Pad0.72x0.64mm_HandSolder
R4, R5, R6: 1.8k; R_0603_1608Metric_Pad0.98x0.95mm_HandSolder
R7: 1.5k; R_0603_1608Metric_Pad0.98x0.95mm_HandSolder
R8: 10k; R_0603_1608Metric_Pad0.98x0.95mm_HandSolder
R9, R12, R13, R14, R19: 0R; R_0603_1608Metric_Pad0.98x0.95mm_HandSolder
R10: 220; R_0603_1608Metric_Pad0.98x0.95mm_HandSolder
R11: 470R; R_0603_1608Metric_Pad0.98x0.95mm_HandSolder
R15: 68R; R_0603_1608Metric_Pad0.98x0.95mm_HandSolder
R16, R17: 0R; R_0201_0603Metric_Pad0.64x0.40mm_HandSolder
R18: 5.1k; R_0603_1608Metric_Pad0.98x0.95mm_HandSolder
TP1: TestPoint; TestPoint_Pad_D1.5mm
TP6, TP7: TestPoint; TestPoint_Pad_D1.0mm
U3: ADF5355BCPZ; CP-32-12_ADI

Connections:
+3.3V: R7.1, R8.1; also elsewhere on the board
/AVDD1: R19.1; also elsewhere on the board
/AVDD2: C23.1, C24.1, U3.16 (AVDD); also elsewhere on the board
/CE: R7.2, U3.4 (CE); also elsewhere on the board
/CLK: R6.1, U3.1 (CLK); also elsewhere on the board
/DATA: R4.1, U3.2 (DATA); also elsewhere on the board
/DVDD: C29.1, C30.1, U3.27 (DVDD); also elsewhere on the board
/LE: R5.1, U3.3 (LE); also elsewhere on the board
/PDBRF: R8.2, U3.26 (PDBRF); also elsewhere on the board
/PLL_Driver/CPOUT: R9.1, U3.7 (CPOUT)
/PLL_Driver/MUX_OUT: R14.2, R15.1
/PLL_Driver/VRF1: C18.1, C19.1, C20.1, C21.1, L2.1, L6.1; also elsewhere on the board
/PLL_Driver/Vtune: R13.2, TP1.1, U3.20 (VTUNE)
/RFIN_A: C16.1; also elsewhere on the board
/RFIN_B: C7.1; also elsewhere on the board
/RF_OUT_A+: C6.2; also elsewhere on the board
/RF_OUT_A-: C3.2; also elsewhere on the board
/RF_OUT_B: C9.1, L4.1; also elsewhere on the board
/VBIAS: C31.1, C32.1, C33.1, U3.24 (VBIAS); also elsewhere on the board
/VP: C34.1, C35.1, U3.6 (VP); also elsewhere on the board
/VREF: C36.1, C37.1, C38.1, U3.23 (VREF); also elsewhere on the board
/VREGVCO: C39.1, C40.1, C41.1, U3.19 (VREGVCO); also elsewhere on the board
/VRF: C42.1, C43.1, C44.1, U3.10 (VRF); also elsewhere on the board
/VVCO: C45.1, C46.1, C47.1, U3.17 (VVCO); also elsewhere on the board
GND: C13.2, C14.2, C15.2, C17.2, C18.2, C19.2, C20.2, C21.2, C22.2, C23.2, C24.2, C25.2, C26.2, C27.2, C28.2, C29.2, C30.2, C31.2, C32.2, C33.2, C34.2, C35.2, C36.2, C37.2, C38.2, C39.2, C40.2, C41.2, C42.2, C43.2, C44.2, C45.2, C46.2, C47.2, D1.1 (K), L1.2, L3.2, L4.2, R4.2, R5.2, R6.2, R10.1, R18.1, U3.8 (CPGND), U3.9 (AGND), U3.13 (AGNDRF), U3.15 (AGNDRF), U3.18 (AGNDVCO), U3.21 (AGNDVCO), U3.31 (SDGND), U3.33 (GND); also elsewhere on the board
unnamed: C3.1, L1.1, L6.2, R16.2
unnamed: C5.1, C7.2, R3.2
unnamed: C6.1, L2.2, L3.1, R17.2
unnamed: C12.1, C13.1, R9.2, R11.1
unnamed: C12.2, R10.2
unnamed: C14.1, R11.2, R12.1
unnamed: C15.1, R12.2, R13.1
unnamed: C8.1, C16.2, R3.1
unnamed: C17.1, C22.1, R19.2, U3.5 (AVDD)
unnamed: D1.2 (A), R15.2
unnamed: R14.1, U3.30 (MUXOUT)
unnamed: C8.2, U3.29 (REFINA)
unnamed: C5.2, U3.28 (REFINB)
unnamed: R17.1, U3.11 (RFOUTA+)
unnamed: R16.1, U3.12 (RFOUTA-)
unnamed: C9.2, U3.14 (RFOUTB)
unnamed: C25.1, C26.1, TP7.1, U3.25 (CREG1)
unnamed: C27.1, C28.1, TP6.1, U3.32 (CREG2)
unnamed: R18.2, U3.22 (RSET)

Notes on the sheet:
PDBRF: -Active low -> disable RFout A+/-
Power Notes: -DVDD=3V3 -VBIAS=NC -VP,VVCO,VREGCO = 5V -VREF=NC -VRF=AVDD=3.3V
Power Notes: -VRF=3V3
PLL Digital & RFIO

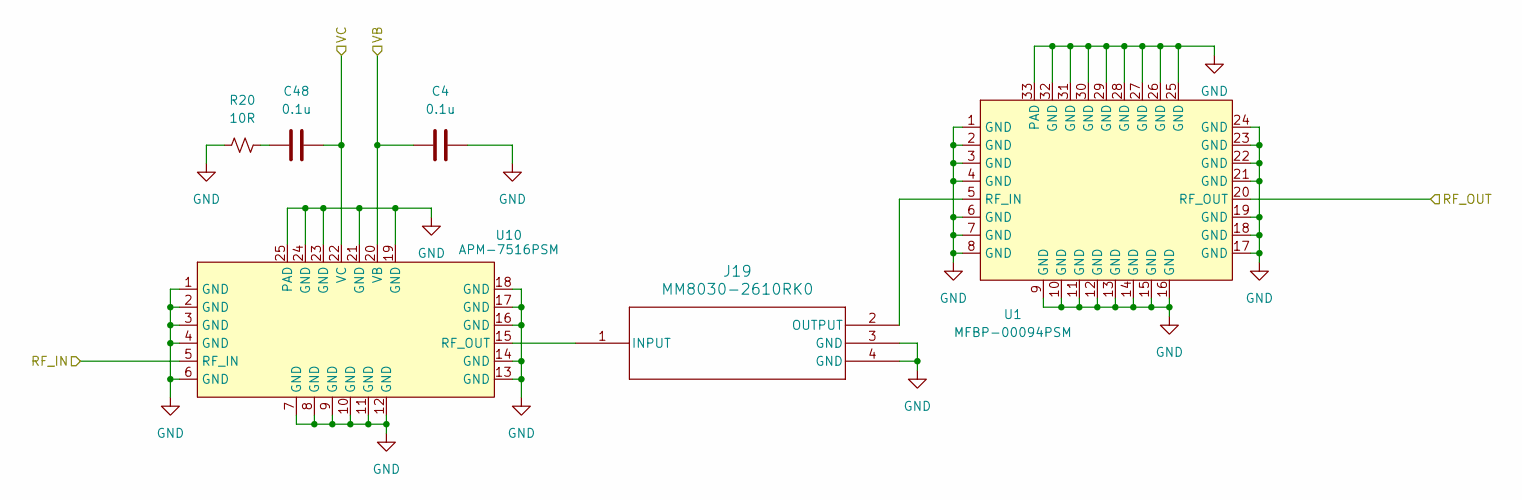
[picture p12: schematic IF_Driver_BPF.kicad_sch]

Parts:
C4, C48: 0.1u; C_0402_1005Metric_Pad0.74x0.62mm_HandSolder
J19: MM8030-2610RK0; MM8030-2610RK0_MUR
R20: 10R; R_0402_1005Metric_Pad0.72x0.64mm_HandSolder
U1: MFBP-00094PSM; QFN-32_EP_5x5_Pitch0.5mm
U10: APM-7516PSM; QFN-24_EP_4x4_Pitch0.5mm

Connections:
/IF_5V: C4.1, C48.2, U10.20 (VB), U10.22 (VC); also elsewhere on the board
/IF_Driver_BPF/RF_OUT: U1.20 (RF_OUT); also elsewhere on the board
/IF_IN: U10.5 (RF_IN); also elsewhere on the board
GND: C4.2, J19.3 (GND), J19.4 (GND), R20.1, U1.1 (GND), U1.2 (GND), U1.3 (GND), U1.4 (GND), U1.6 (GND), U1.7 (GND), U1.8 (GND), U1.9 (GND), U1.10 (GND), U1.11 (GND), U1.12 (GND), U1.13 (GND), U1.14 (GND), U1.15 (GND), U1.16 (GND), U1.17 (GND), U1.18 (GND), U1.19 (GND), U1.21 (GND), U1.22 (GND), U1.23 (GND), U1.24 (GND), U1.25 (GND), U1.26 (GND), U1.27 (GND), U1.28 (GND), U1.29 (GND), U1.30 (GND), U1.31 (GND), U1.32 (GND), U1.33 (PAD), U10.1 (GND), U10.2 (GND), U10.3 (GND), U10.4 (GND), U10.6 (GND), U10.7 (GND), U10.8 (GND), U10.9 (GND), U10.10 (GND), U10.11 (GND), U10.12 (GND), U10.13 (GND), U10.14 (GND), U10.16 (GND), U10.17 (GND), U10.18 (GND), U10.19 (GND), U10.21 (GND), U10.23 (GND), U10.24 (GND), U10.25 (PAD); also elsewhere on the board
unnamed: C48.1, R20.2
unnamed: J19.1 (INPUT), U10.15 (RF_OUT)
unnamed: J19.2 (OUTPUT), U1.5 (RF_IN)

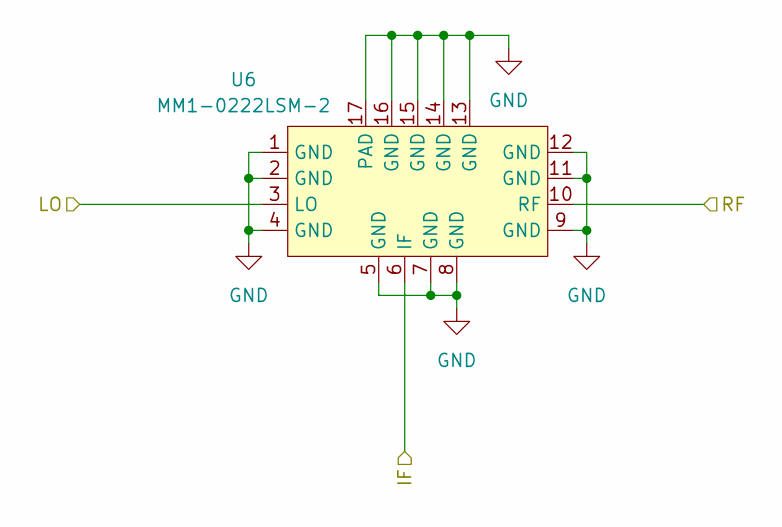
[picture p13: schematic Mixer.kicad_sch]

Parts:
U6: MM1-0222LSM-2; QFN-16_EP_3x3_Pitch0.5mm

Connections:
/Mixer/IF: U6.6 (IF); also elsewhere on the board
/Mixer/LO: U6.3 (LO); also elsewhere on the board
/Mixer/RF: U6.10 (RF); also elsewhere on the board
GND: U6.1 (GND), U6.2 (GND), U6.4 (GND), U6.5 (GND), U6.7 (GND), U6.8 (GND), U6.9 (GND), U6.11 (GND), U6.12 (GND), U6.13 (GND), U6.14 (GND), U6.15 (GND), U6.16 (GND), U6.17 (PAD); also elsewhere on the board

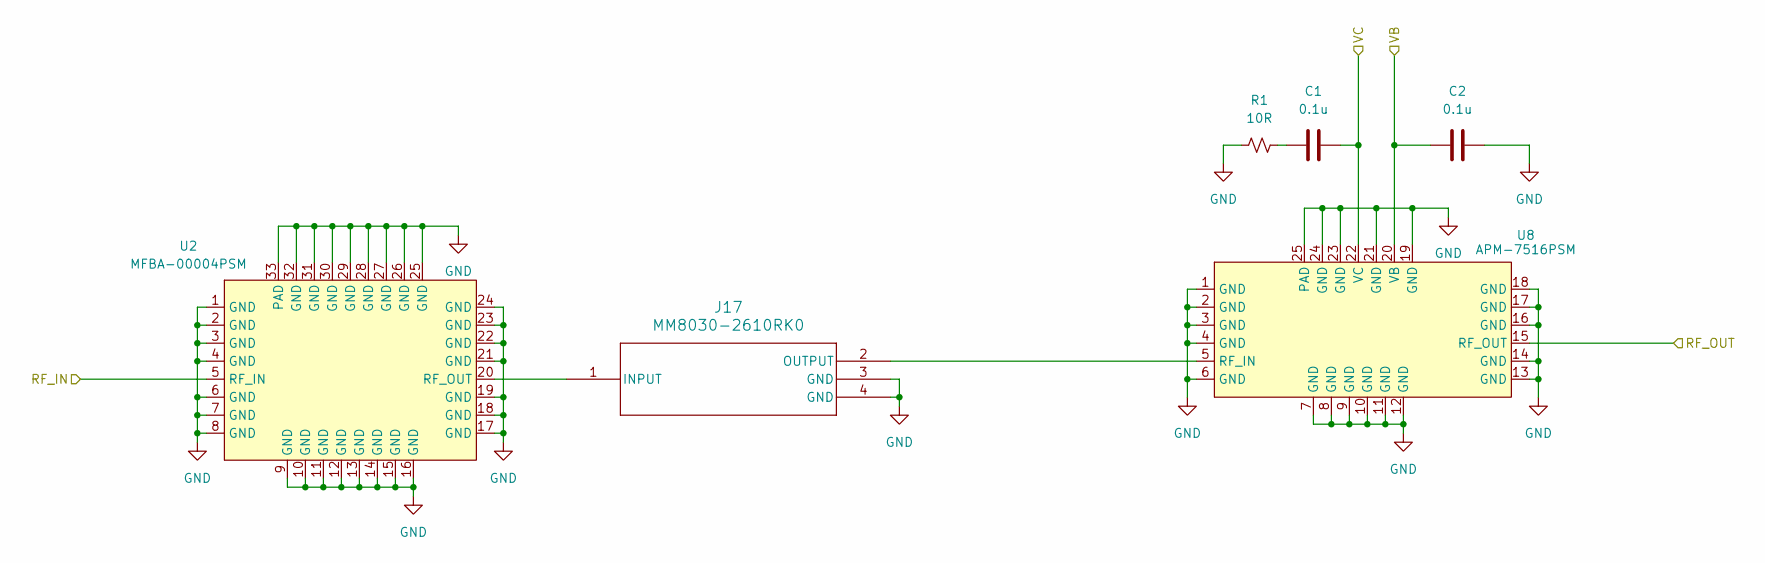
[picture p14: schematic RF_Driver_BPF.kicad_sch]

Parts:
C1, C2: 0.1u; C_0402_1005Metric_Pad0.74x0.62mm_HandSolder
J17: MM8030-2610RK0; MM8030-2610RK0_MUR
R1: 10R; R_0402_1005Metric_Pad0.72x0.64mm_HandSolder
U2: MFBA-00004PSM; QFN-32_EP_5x5_Pitch0.5mm
U8: APM-7516PSM; QFN-24_EP_4x4_Pitch0.5mm

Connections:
/RF_5V: C1.2, C2.1, U8.20 (VB), U8.22 (VC); also elsewhere on the board
/RF_Driver_BPF/RF_IN: U2.5 (RF_IN); also elsewhere on the board
/RF_OUT: U8.15 (RF_OUT); also elsewhere on the board
GND: C2.2, J17.3 (GND), J17.4 (GND), R1.1, U2.1 (GND), U2.2 (GND), U2.3 (GND), U2.4 (GND), U2.6 (GND), U2.7 (GND), U2.8 (GND), U2.9 (GND), U2.10 (GND), U2.11 (GND), U2.12 (GND), U2.13 (GND), U2.14 (GND), U2.15 (GND), U2.16 (GND), U2.17 (GND), U2.18 (GND), U2.19 (GND), U2.21 (GND), U2.22 (GND), U2.23 (GND), U2.24 (GND), U2.25 (GND), U2.26 (GND), U2.27 (GND), U2.28 (GND), U2.29 (GND), U2.30 (GND), U2.31 (GND), U2.32 (GND), U2.33 (PAD), U8.1 (GND), U8.2 (GND), U8.3 (GND), U8.4 (GND), U8.6 (GND), U8.7 (GND), U8.8 (GND), U8.9 (GND), U8.10 (GND), U8.11 (GND), U8.12 (GND), U8.13 (GND), U8.14 (GND), U8.16 (GND), U8.17 (GND), U8.18 (GND), U8.19 (GND), U8.21 (GND), U8.23 (GND), U8.24 (GND), U8.25 (PAD); also elsewhere on the board
unnamed: C1.1, R1.2
unnamed: J17.1 (INPUT), U2.20 (RF_OUT)
unnamed: J17.2 (OUTPUT), U8.5 (RF_IN)

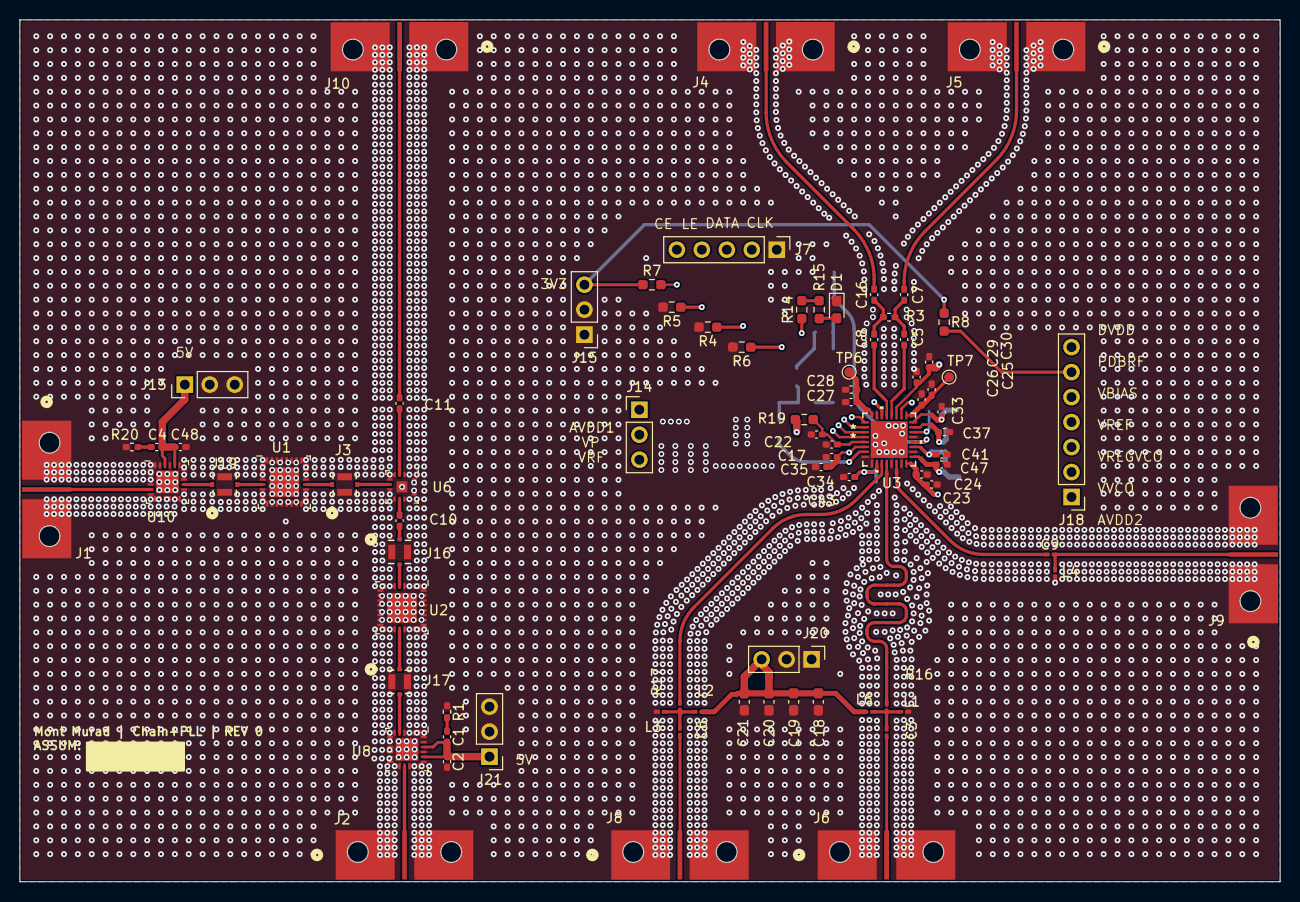
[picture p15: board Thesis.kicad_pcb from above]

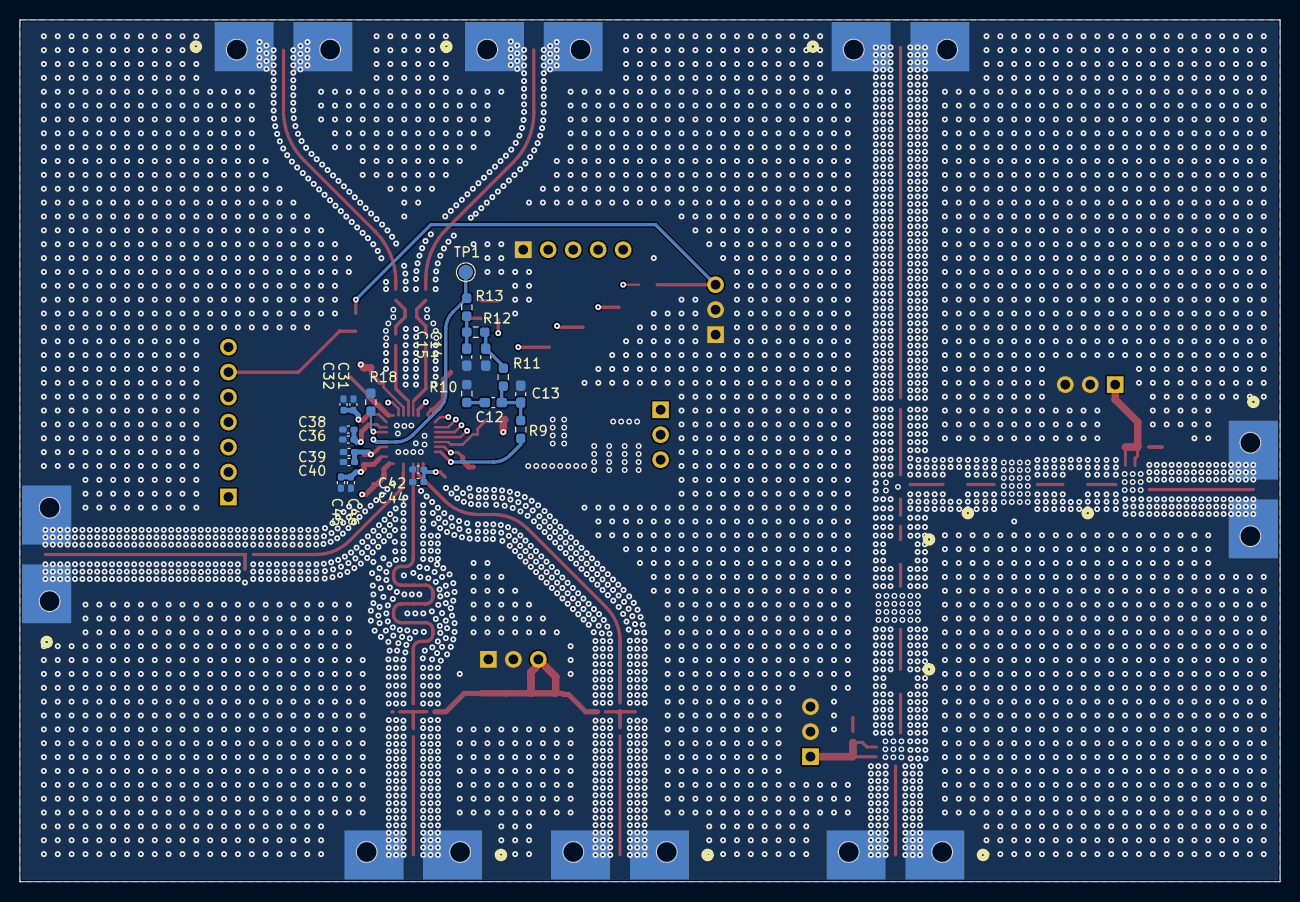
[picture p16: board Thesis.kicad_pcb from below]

Board: 4 copper layers, 128.1 x 87.6 mm, 101 parts (21 on the bottom side), 61 nets.

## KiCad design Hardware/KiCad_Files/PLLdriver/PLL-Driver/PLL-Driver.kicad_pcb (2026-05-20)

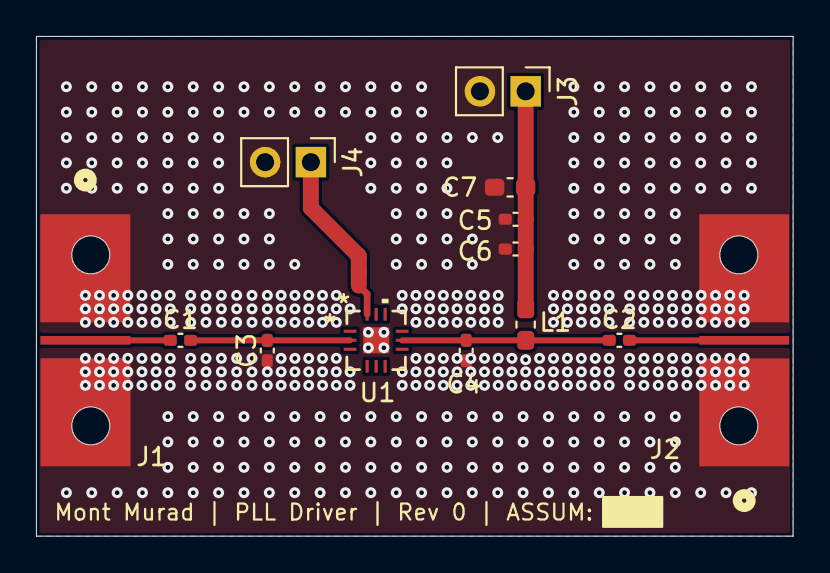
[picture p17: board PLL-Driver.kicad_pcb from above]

Board: 4 copper layers, 42.0 x 27.8 mm, 13 parts (0 on the bottom side), 7 nets.

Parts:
C1, C2: 100p; C_0402_1005Metric_Pad0.74x0.62mm_HandSolder
C3, C4: 0.3p; C_0402_1005Metric_Pad0.74x0.62mm_HandSolder
C5: 10p; C_0402_1005Metric_Pad0.74x0.62mm_HandSolder
C6: 1u; C_0402_1005Metric_Pad0.74x0.62mm_HandSolder
C7: 10u; C_0603_1608Metric_Pad1.08x0.95mm_HandSolder
J1, J2: 32K243-40ML5; CONN_32K243-40ML5_RBG
J3, J4: Conn_01x02_Pin; PinHeader_1x02_P2.54mm_Vertical
L1: 33nH; L_0603_1608Metric_Pad1.05x0.95mm_HandSolder
U1: PMA3-83MP+; DQ1225_MNC

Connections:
/RFIN: C1.1, J1.1
/RFOUT: C2.2, J2.1
/VDD: C5.2, C6.2, C7.2, J3.1, L1.1
/Vladj: J4.1, U1.12 (ladj)
GND: C3.1, C4.1, C5.1, C6.1, C7.1, J1.2, J1.3, J1.4, J1.5, J2.2, J2.3, J2.4, J2.5, J3.2, J4.2, U1.13 (GND)
unnamed: C1.2, C3.2, U1.2 (RF-IN)
unnamed: C2.1, C4.2, L1.2, U1.8 (RF-OUT/VDD)

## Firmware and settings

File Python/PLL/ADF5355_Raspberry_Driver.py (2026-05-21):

#!/usr/bin/env python3
"""
ADF5355 programmer for Raspberry Pi SPI0
Target setup:
- 50 MHz external single-ended reference
- RFOUTB enabled
- RFOUTA disabled
- Output = 7.6 GHz on RFOUTB
- MUXOUT = digital lock detect

Pi wiring (BCM numbering):
- GPIO10 (MOSI) -> DATA
- GPIO11 (SCLK) -> CLK
- GPIO8  (CE0)  -> LE
- GPIO25        -> CE   (optional; set GPIO_CE=None if CE is hard-wired high)
- GPIO24        -> MUXOUT (optional lock-detect input)
"""

import math
import time
import spidev

try:
    import RPi.GPIO as GPIO
    HAVE_GPIO = True
except ImportError:
    HAVE_GPIO = False


# -----------------------------
# User config
# -----------------------------
SPI_BUS = 0
SPI_DEV = 0
SPI_SPEED_HZ = 1_000_000
SPI_MODE = 0

GPIO_CE = 25         # Set to None if ADF5355 CE is tied high
GPIO_MUXOUT = 24     # Set to None if unused

REF_HZ = 50_000_000
TARGET_RFOUTB_HZ = 7_600_000_000

R_COUNTER = 1
REF_DOUBLER = 0
REF_DIV2 = 0

# Charge pump current code: 0..15
CP_CURRENT_CODE = 2

# RFOUTA power code: 0=-4 dBm, 1=-1 dBm, 2=+2 dBm, 3=+5 dBm
RFOUTA_POWER_CODE = 0

# Disable mute-till-lock during debug
MUTE_TILL_LOCK = 0


# -----------------------------
# ADF5355 constants
# -----------------------------
MOD1 = 1 << 24
MAX_MOD2 = 0x3FFF
RFOUTB_MIN_HZ = 6_800_000_000
RFOUTB_MAX_HZ = 13_600_000_000


# -----------------------------
# Register bit helpers
# -----------------------------
def reg0_int(x): return ((x & 0xFFFF) << 4)
def reg0_prescaler(x): return ((x & 0x1) << 20)
def reg0_autocal(x): return ((x & 0x1) << 21)

def reg1_frac1(x): return ((x & 0xFFFFFF) << 4)

def reg2_mod2(x): return ((x & 0x3FFF) << 4)
def reg2_frac2(x): return ((x & 0x3FFF) << 18)

def reg3_phase(x): return ((x & 0xFFFFFF) << 4)
def reg3_phase_adjust(x): return ((x & 0x1) << 28)
def reg3_phase_resync(x): return ((x & 0x1) << 29)
def reg3_exact_sdload_reset(x): return ((x & 0x1) << 30)

def reg4_counter_reset_en(x): return ((x & 0x1) << 4)
def reg4_cp_threestate_en(x): return ((x & 0x1) << 5)
def reg4_power_down_en(x): return ((x & 0x1) << 6)
def reg4_pd_polarity_pos(x): return ((x & 0x1) << 7)
def reg4_mux_logic(x): return ((x & 0x1) << 8)          # 1 = 3.3 V
def reg4_refin_mode_diff(x): return ((x & 0x1) << 9)    # 0 = single-ended
def reg4_charge_pump_curr(x): return ((x & 0xF) << 10)
def reg4_double_buff_en(x): return ((x & 0x1) << 14)
def reg4_r_counter(x): return ((x & 0x3FF) << 15)
def reg4_rdiv2_en(x): return ((x & 0x1) << 25)
def reg4_rmult2_en(x): return ((x & 0x1) << 26)
def reg4_muxout(x): return ((x & 0x7) << 27)

MUXOUT_THREESTATE = 0
MUXOUT_DVDD = 1
MUXOUT_GND = 2
MUXOUT_R_DIV_OUT = 3
MUXOUT_N_DIV_OUT = 4
MUXOUT_ANALOG_LOCK_DETECT = 5
MUXOUT_DIGITAL_LOCK_DETECT = 6

REG5_DEFAULT = 0x00800025

def reg6_output_power(x): return ((x & 0x3) << 4)       # RFOUTA power
def reg6_rfouta_enable(x): return ((x & 0x1) << 6)      # 1 = enable RFOUTA
def reg6_rfoutb_disable(x): return ((x & 0x1) << 10)    # 0 = enable RFOUTB
def reg6_mute_till_lock(x): return ((x & 0x1) << 11)
def reg6_cp_bleed_curr(x): return ((x & 0xFF) << 13)
def reg6_rf_div_sel(x): return ((x & 0x7) << 21)
def reg6_feedback_fund(x): return ((x & 0x1) << 24)
def reg6_neg_bleed_en(x): return ((x & 0x1) << 29)
def reg6_gated_bleed_en(x): return ((x & 0x1) << 30)

REG6_DEFAULT = 0x14000006

def reg7_ld_mode_int_n_en(x): return ((x & 0x1) << 4)
def reg7_frac_n_ld_precision(x): return ((x & 0x3) << 5)
def reg7_lol_mode_en(x): return ((x & 0x1) << 7)
def reg7_ld_cycle_cnt(x): return ((x & 0x3) << 8)
def reg7_le_synced_refin_en(x): return ((x & 0x1) << 25)

REG7_DEFAULT = 0x10000007
REG8_DEFAULT = 0x102D0428

def reg9_synth_lock_timeout(x): return ((x & 0x1F) << 4)
def reg9_alc_timeout(x): return ((x & 0x1F) << 9)
def reg9_timeout(x): return ((x & 0x3FF) << 14)
def reg9_vco_band_div(x): return ((x & 0xFF) << 24)

def reg10_adc_en(x): return ((x & 0x1) << 4)
def reg10_adc_conv_en(x): return ((x & 0x1) << 5)
def reg10_adc_clk_div(x): return ((x & 0xFF) << 6)

REG10_DEFAULT = 0x00C0000A
REG11_DEFAULT = 0x0061300B

def reg12_phase_resync_clk_div(x): return ((x & 0xFFFF) << 16)

REG12_DEFAULT = 0x0000041C


# -----------------------------
# Utility helpers
# -----------------------------
def ceil_div(a, b):
    return (a + b - 1) // b

def clamp(x, lo, hi):
    return max(lo, min(hi, x))

def gcd(a, b):
    while b:
        a, b = b, a % b
    return a

def calc_fpfd_hz():
    return REF_HZ * (1 + REF_DOUBLER) // (R_COUNTER * (1 + REF_DIV2))


# -----------------------------
# PLL math
# -----------------------------
def compute_n_params_for_rfoutb(target_rfoutb_hz):
    if not (RFOUTB_MIN_HZ <= target_rfoutb_hz <= RFOUTB_MAX_HZ):
        raise ValueError(
            f"RFOUTB must be in [{RFOUTB_MIN_HZ}, {RFOUTB_MAX_HZ}] Hz"
        )

    # ADF5355 RFOUTB = 2 * VCO
    vco_hz = target_rfoutb_hz // 2
    fpfd_hz = calc_fpfd_hz()

    n_num = vco_hz
    n_den = fpfd_hz

    integer = n_num // n_den
    remainder_hz = n_num % n_den

    if remainder_hz == 0:
        frac1 = 0
        frac2 = 0
        mod2 = 2
    else:
        frac1_full_num = remainder_hz * MOD1
        frac1 = frac1_full_num // n_den
        rem_after_frac1 = frac1_full_num % n_den

        mod2 = fpfd_hz
        frac2 = int(round(rem_after_frac1 * mod2 / n_den))

        while mod2 > MAX_MOD2:
            mod2 >>= 1
            frac2 >>= 1

        if frac2 == mod2:
            frac1 += 1
            frac2 = 0

        if frac2 != 0:
            d = gcd(frac2, mod2)
            frac2 //= d
            mod2 //= d
        else:
            mod2 = 2

    prescaler = 1 if integer >= 75 else 0

    return {
        "rfoutb_hz": target_rfoutb_hz,
        "vco_hz": vco_hz,
        "fpfd_hz": fpfd_hz,
        "int": integer,
        "frac1": frac1,
        "frac2": frac2,
        "mod2": mod2,
        "prescaler": prescaler,
        "rf_div_sel": 0,      # /1
    }


# -----------------------------
# Build registers
# -----------------------------
def build_regs(target_rfoutb_hz):
    p = compute_n_params_for_rfoutb(target_rfoutb_hz)

    regs = [0] * 13

    # R0
    regs[0] = (
        reg0_int(p["int"]) |
        reg0_prescaler(p["prescaler"]) |
        reg0_autocal(1) |
        0x0
    )

    # R1
    regs[1] = (
        reg1_frac1(p["frac1"]) |
        0x1
    )

    # R2
    regs[2] = (
        reg2_frac2(p["frac2"]) |
        reg2_mod2(p["mod2"]) |
        0x2
    )

    # R3
    regs[3] = (
        reg3_phase(1) |
        reg3_phase_adjust(0) |
        reg3_phase_resync(0) |
        reg3_exact_sdload_reset(0) |
        0x3
    )

    # R4
    regs[4] = (
        reg4_counter_reset_en(0) |
        reg4_cp_threestate_en(0) |
        reg4_power_down_en(0) |
        reg4_pd_polarity_pos(1) |
        reg4_mux_logic(1) |
        reg4_refin_mode_diff(0) |
        reg4_charge_pump_curr(CP_CURRENT_CODE) |
        reg4_double_buff_en(1) |
        reg4_r_counter(R_COUNTER) |
        reg4_rdiv2_en(REF_DIV2) |
        reg4_rmult2_en(REF_DOUBLER) |
        reg4_muxout(MUXOUT_DIGITAL_LOCK_DETECT) |
        0x4
    )

    # R5
    regs[5] = REG5_DEFAULT

    # R6
    regs[6] = (
        REG6_DEFAULT |
        reg6_output_power(RFOUTA_POWER_CODE) |
        reg6_rfouta_enable(0) |
        reg6_rfoutb_disable(0) |
        reg6_mute_till_lock(MUTE_TILL_LOCK) |
        reg6_cp_bleed_curr(0) |
        reg6_rf_div_sel(p["rf_div_sel"]) |
        reg6_feedback_fund(1) |
        reg6_neg_bleed_en(0) |
        reg6_gated_bleed_en(0)
    )

    # R7
    regs[7] = (
        REG7_DEFAULT |
        reg7_ld_mode_int_n_en(1) |
        reg7_frac_n_ld_precision(0) |
        reg7_lol_mode_en(0) |
        reg7_ld_cycle_cnt(0) |
        reg7_le_synced_refin_en(1)
    )

    # R8
    regs[8] = REG8_DEFAULT

    # R9
    fpfd = p["fpfd_hz"]
    timeout = clamp(ceil_div(fpfd, 20_000 * 30), 1, 1023)
    synth_lock_timeout = clamp(ceil_div(fpfd * 2, 100_000 * timeout), 1, 31)
    alc_timeout = clamp(ceil_div(fpfd * 5, 100_000 * timeout), 1, 31)
    vco_band_div = clamp(ceil_div(fpfd, 2_400_000), 1, 255)

    regs[9] = (
        reg9_synth_lock_timeout(synth_lock_timeout) |
        reg9_alc_timeout(alc_timeout) |
        reg9_timeout(timeout) |
        reg9_vco_band_div(vco_band_div) |
        0x9
    )

    # R10
    adc_div = clamp(math.ceil((fpfd / 100_000 - 2) / 4), 1, 255)

    regs[10] = (
        REG10_DEFAULT |
        reg10_adc_en(1) |
        reg10_adc_conv_en(1) |
        reg10_adc_clk_div(adc_div)
    )

    # R11
    regs[11] = REG11_DEFAULT

    # R12
    regs[12] = (
        REG12_DEFAULT |
        reg12_phase_resync_clk_div(1)
    )

    # Conservative delay >16 ADC clocks
    adc_clk = fpfd / (4 * adc_div + 2)
    delay_us = max(200, math.ceil((16 / adc_clk) * 1_000_000))

    info = {
        **p,
        "timeout": timeout,
        "synth_lock_timeout": synth_lock_timeout,
        "alc_timeout": alc_timeout,
        "vco_band_div": vco_band_div,
        "adc_div": adc_div,
        "delay_us": delay_us,
    }

    return regs, info


# -----------------------------
# SPI / GPIO
# -----------------------------
def spi_write_reg(spi, regval):
    spi.xfer2([
        (regval >> 24) & 0xFF,
        (regval >> 16) & 0xFF,
        (regval >> 8) & 0xFF,
        regval & 0xFF,
    ])

def setup_gpio():
    if not HAVE_GPIO:
        return

    GPIO.setmode(GPIO.BCM)

    if GPIO_CE is not None:
        GPIO.setup(GPIO_CE, GPIO.OUT, initial=GPIO.LOW)

    if GPIO_MUXOUT is not None:
        GPIO.setup(GPIO_MUXOUT, GPIO.IN)

def cleanup_gpio():
    if HAVE_GPIO:
        GPIO.cleanup()

def pll_enable():
    if HAVE_GPIO and GPIO_CE is not None:
        GPIO.output(GPIO_CE, GPIO.HIGH)

def pll_disable():
    if HAVE_GPIO and GPIO_CE is not None:
        GPIO.output(GPIO_CE, GPIO.LOW)

def read_muxout():
    if HAVE_GPIO and GPIO_MUXOUT is not None:
        return GPIO.input(GPIO_MUXOUT)
    return None


# -----------------------------
# Programming sequences
# -----------------------------
def initial_program(spi, regs, delay_us):
    # fPFD <= 75 MHz sequence: R12 ... R1, wait, then R0
    for reg_num in range(12, 0, -1):
        spi_write_reg(spi, regs[reg_num])

    time.sleep(delay_us / 1_000_000.0)
    spi_write_reg(spi, regs[0])

def frequency_update(spi, regs, delay_us):
    # fPFD <= 75 MHz update sequence
    r4_reset_on = (regs[4] | reg4_counter_reset_en(1))
    r4_reset_off = (regs[4] & ~reg4_counter_reset_en(1))
    r0_autocal_off = (regs[0] & ~reg0_autocal(1))
    r0_autocal_on = regs[0]

    spi_write_reg(spi, regs[10])
    spi_write_reg(spi, r4_reset_on)
    spi_write_reg(spi, regs[2])
    spi_write_reg(spi, regs[1])
    spi_write_reg(spi, r0_autocal_off)
    spi_write_reg(spi, r4_reset_off)
    time.sleep(delay_us / 1_000_000.0)
    spi_write_reg(spi, r0_autocal_on)

def dump_regs(regs):
    for i in range(12, -1, -1):
        print(f"R{i:02d} = 0x{regs[i]:08X}")


# -----------------------------
# Main
# -----------------------------
def main():
    regs, info = build_regs(TARGET_RFOUTB_HZ)

    print("ADF5355 target config")
    print(f"  REF input      : {REF_HZ} Hz")
    print(f"  PFD            : {info['fpfd_hz']} Hz")
    print(f"  RFOUTB target  : {info['rfoutb_hz']} Hz")
    print(f"  VCO            : {info['vco_hz']} Hz")
    print(f"  INT            : {info['int']}")
    print(f"  FRAC1          : {info['frac1']}")
    print(f"  FRAC2          : {info['frac2']}")
    print(f"  MOD2           : {info['mod2']}")
    print(f"  RF divider     : /{1 << info['rf_div_sel']}")
    print(f"  Delay          : {info['delay_us']} us")
    print()
    dump_regs(regs)
    print()

    spi = spidev.SpiDev()
    spi.open(SPI_BUS, SPI_DEV)
    spi.max_speed_hz = SPI_SPEED_HZ
    spi.mode = SPI_MODE
    spi.bits_per_word = 8

    try:
        setup_gpio()
        pll_disable()
        time.sleep(0.01)
        pll_enable()
        time.sleep(0.01)

        initial_program(spi, regs, info["delay_us"])
        time.sleep(0.05)

        ld = read_muxout()
        print("Initial program done.")
        if ld is not None:
            print(f"MUXOUT lock-detect = {ld}")

    finally:
        spi.close()
        cleanup_gpio()


if __name__ == "__main__":
    main()

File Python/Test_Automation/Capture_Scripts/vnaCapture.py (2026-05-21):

"""
Screen Capture of the HP5262A VNA
    - This script will simply return a CSV and a plot of the screen.
    - The CSV is a colletction of all s-parameters in real an imag
    - This script will always capture all 4 parameters
"""

import pyvisa
import numpy as np
import matplotlib.pyplot as plt
import time
import re
from datetime import datetime

# ---------------------------
# USER SETTINGS
# ---------------------------
GPIB_ADDRESS = "GPIB0::16::INSTR"
TIMEOUT_MS = 60000
S_PARAMS = ["S11", "S21", "S12", "S22"]

# ---------------------------
# HELPERS
# ---------------------------
def q_float(inst, cmd):
    return float(inst.query(cmd).strip())

def q_int(inst, cmd):
    return int(float(inst.query(cmd).strip()))

def q_str(inst, cmd, default="UNKNOWN"):
    try:
        return inst.query(cmd).strip()
    except Exception:
        return default

def sanitize(text):
    return re.sub(r'[^A-Za-z0-9_.-]+', '_', text)

def read_trace_ascii(inst):
    inst.write("OUTPDATA")
    time.sleep(0.5)

    raw = inst.read_raw()
    text = raw.decode(errors="ignore")

    nums = re.findall(r'[-+]?(?:\d+\.\d*|\.\d+|\d+)(?:[Ee][-+]?\d+)?', text)
    vals = np.array([float(x) for x in nums], dtype=float)

    return vals

# ---------------------------
# CONNECT
# ---------------------------
rm = pyvisa.ResourceManager()
vna = rm.open_resource(GPIB_ADDRESS)

vna.timeout = TIMEOUT_MS
vna.write_termination = "\n"
vna.read_termination = "\n"

# ---------------------------
# SETUP
# ---------------------------
vna.write("FORM4")

f_start = q_float(vna, "STAR?")
f_stop  = q_float(vna, "STOP?")
npts    = q_int(vna, "POIN?")
ifbw    = q_str(vna, "IFBW?")

freq_hz = np.linspace(f_start, f_stop, npts)

print(f"Start: {f_start} Hz | Stop: {f_stop} Hz | Points: {npts}")
print(f"IFBW: {ifbw}")

# ---------------------------
# READ DATA
# ---------------------------
results = {}

for sp in S_PARAMS:
    print(f"Reading {sp}...")

    vna.write(f"CHAN1;{sp};LOGM")
    vna.write("SING")
    time.sleep(2.0)

    vna.read_termination = None
    vals = read_trace_ascii(vna)
    vna.read_termination = "\n"

    if len(vals) != 2 * npts:
        raise RuntimeError(f"{sp}: expected {2*npts}, got {len(vals)}")

    results[sp] = vals[0::2] + 1j * vals[1::2]

# ---------------------------
# BUILD ARRAY FOR SAVING
# ---------------------------
data = np.column_stack([
    freq_hz,
    results["S11"].real, results["S11"].imag,
    results["S21"].real, results["S21"].imag,
    results["S12"].real, results["S12"].imag,
    results["S22"].real, results["S22"].imag,
])

# ---------------------------
# FILENAME
# ---------------------------
date_str = datetime.now().strftime("%Y-%m-%d")
fileLocation = r"replace_this_with_your_directory"  # Replace with directory to save to
fname = fileLocation + f"\{date_str}_{sanitize(GPIB_ADDRESS)}_replace_with_your_name.csv" # Replace with file name

# ---------------------------
# HEADER (for savetxt)
# ---------------------------
header = (
    f"Date: {date_str}\n"
    f"IFBW: {ifbw}\n"
    f"GPIB: {GPIB_ADDRESS}\n"
    f"Start_Hz: {f_start}\n"
    f"Stop_Hz: {f_stop}\n"
    f"Points: {npts}\n"
    "Columns:\n"
    "Freq_Hz, "
    "S11_Re, S11_Im, "
    "S21_Re, S21_Im, "
    "S12_Re, S12_Im, "
    "S22_Re, S22_Im"
)

# ---------------------------
# SAVE USING NUMPY
# ---------------------------
np.savetxt(
    fname,
    data,
    delimiter=",",
    header=header,
    comments="CalKitAttenuator_2X10dB"
)

print(f"\nSaved file: {fname}")

# ---------------------------
# PLOT (dB magnitude)
# ---------------------------
plt.figure()

for sp in S_PARAMS:
    mag_db = 20 * np.log10(np.abs(results[sp]))
    plt.plot(freq_hz/1e9, mag_db, label=sp)

plt.xlabel("Frequency (GHz)")
plt.ylabel("Magnitude (dB)")
plt.title("S-Parameters vs Frequency")
plt.legend()
plt.grid()

plt.show()

# ---------------------------
# CLEANUP
# ---------------------------
vna.close()
rm.close()

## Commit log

2026-05-20 Added KiCad Files
    [Converter_Parts.csv, ECS-TXO-2520-33-250-AN-TR.step, EDI2CAP.CFG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]
2026-05-21 filled data, python captures, GNU bpsk and qpsk, added readme where needed
    [2026-04-05_14-12-39_TestSpectrumCapture.csv, 2026-04-05_14-14-27_TestSpectrumCapture.csv, 2026-04-05_14-14-59_TestSpectrumCapture.csv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]
2026-05-21 added BOM of comps
    [Component_BOM.xlsx]
2026-06-11 Added QPSK flow graphs and data
    [2026-05-31_18-18-10_SDR_Spectrum_Spa_5MHz_RBW_30kHz.csv, 2026-05-31_18-19-41_SDR_Spectrum_Spa_5MHz_RBW_30kHz_MAXHOLD.csv, 2026-05-31_18-25-39_SDR_Mixer_Spectru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]
